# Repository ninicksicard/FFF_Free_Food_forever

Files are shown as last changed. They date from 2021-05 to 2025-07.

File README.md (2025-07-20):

# FFF_Free_Food_forever

bioreactor

Automated spirulina bioreactor. When your refrigerator also make your food.
 
This is my take on solving world unger.

Spirulina is nutritive, cheap and easy to grow. Making a spirulina bioreactor could continuously produce a food source with minimal ressources.

Current status : 
working prototype with some manual input. 
Total cost is less than 220$ and can be lowered.
working cost is pretty low : 
  less than 7$/month of electricity
  cost of growth medium is uncertain now. seems to be less than 30$/months.
  in canada, water is free, but elsewhere it should be taken into account.

---> See the Fabrication Guide pdf for a better look <----

To make your own : 
1. gather all the parts listed in the parts list.

2. order a pcb on jlcpcb with the Gerber Files for the motherboard
diagram
pcbdiagram
PCB
3. order a spirulina starter kit or get some live culture from a friend. 
sample backup
4. assemble the parts following the instructions. electronic soldering is required.

5. load the software on the microcontroller following instructions. 


6. prepare the growth medium and make sure the system is working properly.
7. begin spirulina culture.
first inoculation
8. wait until the population is dense enough
100x spirulina microscope(streight strain) (2)
9. consume the extracted spirulina every days or discard the surplus.


Spirulina reliability as food source.
It is far from a perfect food source, but it is better than fast food. 100L should be barely enough to survive on. 
with a 200L culture, you should produce about 40g of dried spirulina every day. with that amount, following vitamins are produced. (percentage of recommanded daily values)

Vtamin A	retinol 	15%							
Vitamin B1	79%
Vitamin B2	113%
Vitamin B3 32%
Vitamin B5	28%
Vitamin B6	11%
Vitamin B7	125%
Vitamin B9	0%
Vitamin B12	1100%
Vitamin C	4%
Vitamin D 0%
Vitamin E 13%
Vitamin K	9%

As stated, it is definetly not a perfect or proper food source, but it is way better than nothing. Calories should come from some other food, but it is not hard to come-by for cheap. 

Taste 
When rinsed properly, fresh and mixed with water, it feels and taste like drinking water. 

# DIY Spirulina Bioreactor

## Table of Contents
1. [Introduction](#introduction)
2. [Features](#features)
3. [Installation](#installation)
4. [Usage](#usage)
5. [Contribution Guidelines](#contribution)
6. [Troubleshooting](#troubleshooting)
7. [License](#license)
8. [Acknowledgements](#acknowledgements)
9. [Documentation and Data](#docs-data)

## Introduction 
Welcome to the DIY Spirulina Bioreactor project. Spirulina is a nutrient-rich, easy-to-grow microalgae that serves as an excellent food source. Our project aims to tackle world hunger by providing a cost-effective solution: a DIY Spirulina Bioreactor. This bioreactor automates the process of Spirulina cultivation, offering a sustainable food production method with minimal resource requirements.

## Features 
The Spirulina Bioreactor boasts several features:
- Efficient and cheap Spirulina cultivation
- Automated process requiring minimal manual intervention
- Low total and operational costs
- Utilization of sustainable and accessible resources

## Installation 
Setting up your own Spirulina Bioreactor involves a few steps, including gathering necessary parts, ordering a PCB, procuring a Spirulina starter kit, assembling the parts, loading the software on the microcontroller, and preparing the growth medium. Detailed instructions and a list of materials are provided in the [Fabrication Guide](link-to-guide-here) PDF.

## Usage 
Once the setup is complete, the bioreactor can be used to cultivate Spirulina. Detailed instructions on Spirulina cultivation, maintenance, and extraction are provided in the guide. We also provide information on how to handle the harvested Spirulina.

## Contribution Guidelines 
We welcome contributions to improve the project. This could include bug fixes, feature enhancements, or even sharing your experience of building and using the bioreactor. Please make sure to adhere to the project's code of conduct.

## Troubleshooting 
We provide a list of common issues encountered during the setup or usage of the bioreactor, along with their respective solutions. If you face a problem not listed there, please raise an issue, and we'll address it promptly.

## License 
This project is licensed under the MIT license.

## Acknowledgements 
We would like to thank the open-source community for their continuous support and inspiration that made this project possible.

## Documentation and Data 
All supplementary documentation can be found in the `docs/` directory, including fabrication instructions and research papers. Data sets and spreadsheets are now located in the `data/` folder. Media files showing the progression of the project are under `media/`.

---

For further questions or clarifications, please contact us at [email@example.com](mailto:email@example.com).

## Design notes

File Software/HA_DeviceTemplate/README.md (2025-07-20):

# HA_DeviceTemplate

This project provides a skeleton for controlling an ESP32S3 based device with MicroPython.  Use it as a starting point for your own hardware projects.  Wi‑Fi and MQTT credentials are no longer stored in the repository.  Instead they are loaded from environment variables or local configuration files that are ignored by git.

## Configuration

### Wi‑Fi
Wi‑Fi networks are read from a JSON configuration file.  The path can be specified with the environment variable `WIFI_CONFIG_PATH`.  If not set, `/networks.json` is used.  A template file is provided as `networks.example.json`:

```json
{
    "schema": 2,
    "known_networks": [
        { "ssid": "YOUR_WIFI_SSID", "password": "YOUR_WIFI_PASSWORD", "enables_webrepl": false }
    ],
    "access_point": {
        "config": {
            "essid": "Micropython-Dev2",
            "channel": 11,
            "hidden": false,
            "password": "CHANGE_ME"
        },
        "enables_webrepl": false,
        "start_policy": "fallback"
    }
}
```

Copy this file to `networks.json` and fill in your credentials.  Because `networks.json` is listed in `.gitignore`, it will not be committed to version control.

### MQTT
The MQTT client reads its connection settings from environment variables:

- `MQTT_BROKER` – hostname or IP of the broker
- `MQTT_CLIENT_ID` – client identifier (defaults to a value derived from `machine.unique_id` if unset)
- `MQTT_USERNAME` – MQTT username
- `MQTT_PASSWORD` – MQTT password

You can create an optional `.env` or `mqtt_config.json` (both ignored by git) and load the variables before running the code.

An example configuration file is provided as `mqtt_config.example.json`:

```json
{
    "MQTT_BROKER": "mqtt.example.com",
    "MQTT_CLIENT_ID": "ESP32S3_example",
    "MQTT_USERNAME": "homeassistant",
    "MQTT_PASSWORD": "YOUR_MQTT_PASSWORD"
}
```

Copy this file to `mqtt_config.json` and update it with your credentials.

## Running Tests
Run `pytest -q` to execute the test suite (currently empty).

## Print Control
The `print_control` module allows global control over the built-in
`print` function.  Importing the module overrides `print` so you can
disable all output or log it to a file::

    import print_control
    print_control.set_print_enabled(False)
    print("This won't appear on stdout")
    print_control.set_log_to_file(True, "mylog.txt")
    print("This will be written to mylog.txt")

## Stopping Timers
The application schedules most of its work using ``machine.Timer`` instances.
Once ``boot.py`` finishes execution, these timers continue to run in the
background. Pressing ``Ctrl-C`` immediately after boot does **not** stop them
because the boot script has already returned. To clean up running timers from
the REPL, call::

    import bootproc
    bootproc.kill_all_timers()

Alternatively enable automatic cleanup by starting the keyboard interrupt
monitor::

    bootproc.start_keyboard_interrupt_timer()

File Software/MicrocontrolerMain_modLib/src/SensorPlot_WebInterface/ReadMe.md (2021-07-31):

# SensorPlot WebInterface

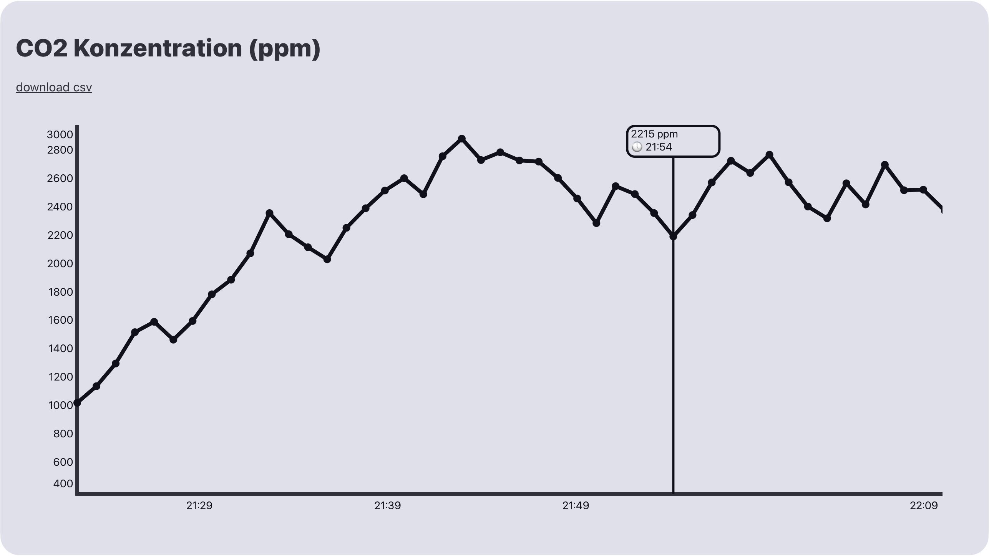
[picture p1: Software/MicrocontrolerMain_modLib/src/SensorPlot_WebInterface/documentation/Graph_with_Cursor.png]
Sensor-Graph with Info-Cursor Image Sensor-Graph with Info-Cursor


## Description
The SensorPlot_WebInterface C++ library is made to be used on any Ardunio like microcontroller to make up a webinterface.
This interface is able to display up to 32 Plot-Graphs which represent sensor measurements. Each graph provides a *download csv* link which triggers a download of a CSV-File, containing all tracked Plot-Data of this sensor.

As a summory on the top is a view, containing the latest sensor measurements and a smiley which represents the state of those values. If they are not good or even bad the smiley changes its mood from happy to neutral or sad. These thresholds, as well as Name, Unit, etc. can be configured when adding a Plot.

By hovering over the graph, the Info-Cursor will show up and display detailed information about the measurement at this time. Displayed will be the exact value and time at which the measurement has been made.

Furthermore the webinterface also supports light and dark mode, automatically detected by the system preferences as well as a mobile and desktop mode, which is determined by the window width. 

---

## How to use it
This project depends on the ESP8266WebServer lib to create the server.
This repo contains a SensorPlot_WebInterface_ConfigExample.ino file where you can check out an easy example how to implement this library.
More detailed information about how to use it are here:

#### Step 1 - configuration
After instantiating the ESP8266WebServer and the SensorPlot_WebInterface you have to call the ``interfaceConfig("title", "input field", "perform action")`` method which takes 3 arguments.
1. The Website Title, wich should be displayed in the browser
2. Input Field, which is the placeholder text for the callback input field in the webinterface
3. Perform Action, which is the text of the button, which triggers the callback with the input field's text as param

#### Step 2 - add plots
Next you have to define all the Sensor-Plots you want to display on the interface. You can add up to 32 of them.
They can be added by calling the ``addPlot("Name", "Unit", interval, goodThreshold, badThreshold, min, max, stepsize, cycleDuration, cycleStepsize, &measurementsCount, measurements, &measurementsTimestamp)`` method which takes 13 arguments.

|Argument | Type | Description|
|--|--|---|
|1. The Sensor Name | String | how this measurement is called (e.g. "CO2 Concentration")|
|2. Sensor Unit | String | what this value is measured in (e.g. "ppm - parts per million")|
|3. Reload Interval | Int | in which interval shoud the webinterface reload the sensore data form the server (often same as cycleDuration)|
|4. lower Threshold | Int | down to which value can this measurement be considered as good|
|5. upper Threshold | Int | up to which value can this measurement be considered as good|
|6. Min Graph-Value | Int | the minimum Y-Axis value that is static on the graph (gets overriden, when reaching this border)|
|7. Max Graph-Value | Int | the maximum Y-Axis value that is static on the graph (gets overriden, when reaching this border)|
|8. Graph Stepsize | Int | at which interval should the Y-Axis labels be displayed (e.g. 0 - 200 - 400 - 600 [stepszie = 200])|
|9. Cycle Duration | Int | in which interval are the values measured in seconds (e.g. cycleDuration = 60 | measurements are 1 minute apart)|
|10. Cycle Stepsize | Int | at which interval should the X-Axis labels be displayed (e.g. cycleStepsize = 300 | the labels are 5 minutes apart)|
|11. Measurements Counter Pointer | *Int | a pointer onto the counter of measurements tracked from this sensor|
|12. Measurements Pointer | *Float | a pointer onto the array containing the measurements from this sensor|
|13. Measurements Timestamp Pointer | *Int | a pointer onto the timestamp of the last measurement done with this sensor (millis since last measurement to calculate the time)|

#### Step 3 - response setup
The final step is to call the ``serverResponseSetup(&server, &callback)`` method which takes just 2 arguments.
1. A pointer onto the ESP8266WebServer
2. A pointer onto a method, returning an int, which gets called when the webinterface triggers the callback.

This callback function receives a String containing the input text from the input field on the website. By checking the input in this method you can trigger or execute any operation you like. Just make sure to return a 0 when the input is invalid and return 1 when it is valid. This will get looped through to the interface and changes the input fields color to green or red.

---

## Why has it been developed
This library was developed as part of an open source project at the Trier University of Applied Sciences Environmental Campus Birkenfeld.
The idea is to provide as many schools, universities as well as private person with a budget friendly way to build their own CO2-Concentration Measurement Stations. This should indicate when it's time to get fresh air, which got even more important throught to the Covid-Pandamic. 
This lib was created to allow a user friendly interaction and to provide an easy way for everyone checking the values of the past couple of hours.

For further information, please check out this website - [CO2 Ampel](http://www.co2ampel.org/)
Here you will find plans and descriptions to build your own device, when you like.

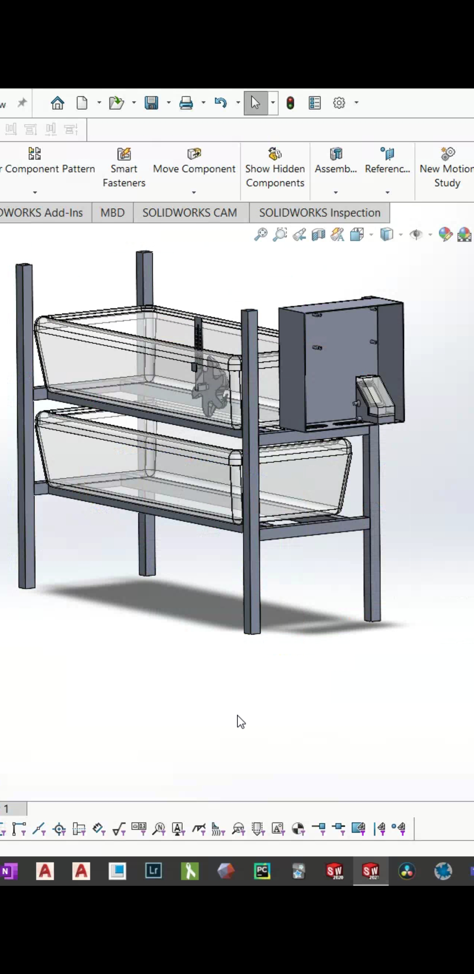
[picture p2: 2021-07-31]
docs/progression medias/3D model concept.jpg

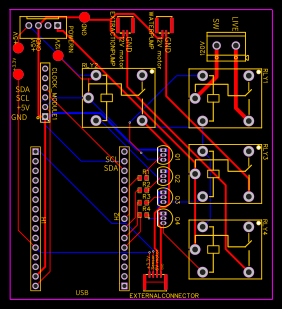
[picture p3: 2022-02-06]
Hardware/electronic/fdd8c61e862d43c1a90568aa42baffc7.png

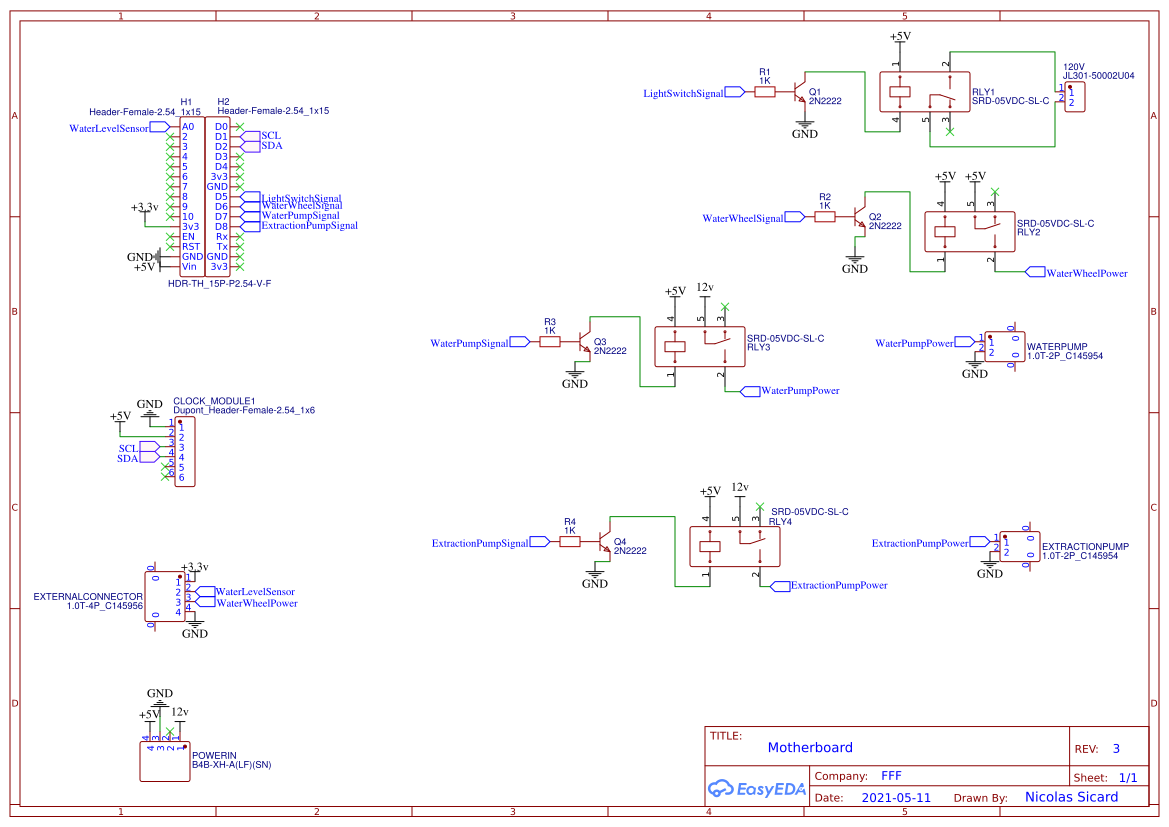
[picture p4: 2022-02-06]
Hardware/electronic/a6cdc383c2d447928fe49a9db9fc658a.png

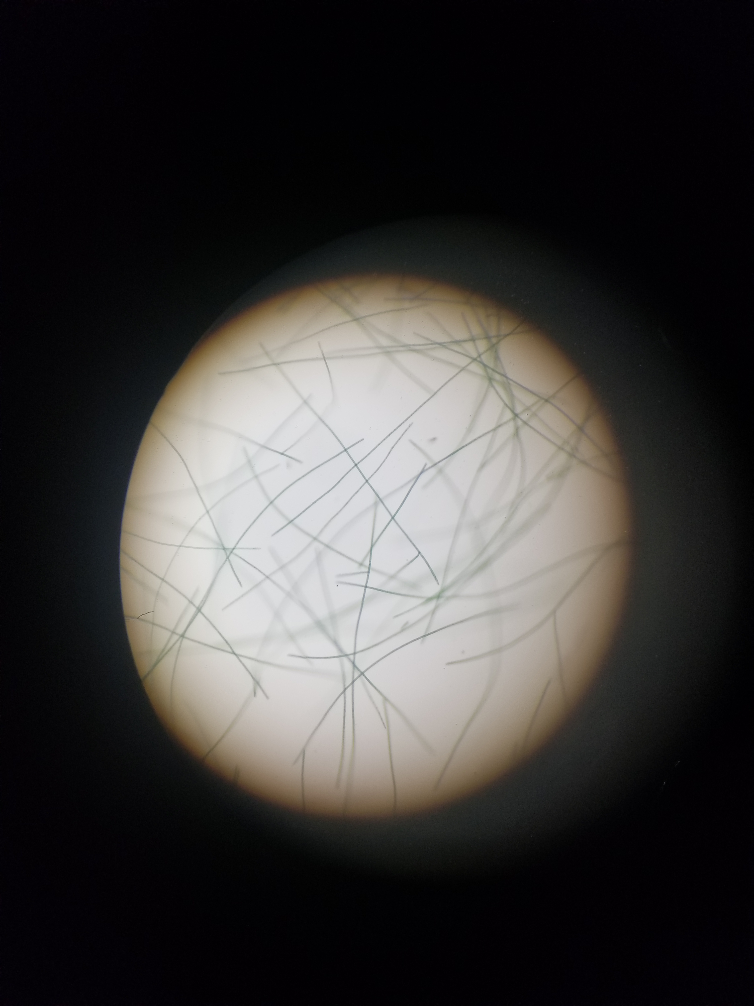
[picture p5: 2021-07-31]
docs/progression medias/100x spirulina microscope(streight strain) (2).jpg

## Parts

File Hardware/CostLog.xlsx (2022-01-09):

 |  | Total |  | $956.63
183.008
selection price | Include | Item | technical name/model number | lot price | lot size or meters | quantity/bioreactor | unit price | url
0 | FALSE | PH Sensor |  | $20.00 | 1 | 1 | $20.00
0 | FALSE | PH Sensor |  | $9.52 | 1 | 1 | $9.52 | https://www.aliexpress.com/item/32813510050.html
0 | FALSE | Thermometer | DS118B20 | $13.00 | 3 | 1 | $4.33
0 | FALSE | Thermometer | DS118B20 | $2.49 | 1 | 1 | $2.49
 | FALSE | resistor for thermometer
0 | FALSE | NodeMcu |  | $6.00 | 1 | 1 | $6.00 | https://www.aliexpress.com/item/2046539452.html
$3.83 | TRUE | NodeMCU |  | $38.28 | 10 | 1 | $3.83
0 | FALSE | Nodemcu |  | $327.74 | 100 | 1 | $3.28
0 | FALSE | Growlight | 100w each 480 needed max | $54.99 | 2 | 4 | $109.98 | https://www.amazon.com/Spectrum-Growing-Vegetables-Greenhouse-Hydroponic/dp/B082QQJ82V
$39.34 | TRUE | Growlight | 100w each 480 needed max | $78.68 | 4 | 2 | $39.34 | https://www.aliexpress.com/item/32847579349.html
$3.42 | TRUE | light socket |  | $1.71 | 1 | 2 | $3.42 | https://www.aliexpress.com/item/1005002524429990.html
0 | FALSE | water pump |  | $30.00 | 1 | 1 | $30.00
0 | FALSE | dosing pump |  | $50.00 | 4 | 3 | $37.50
$10.88 | TRUE | dosing pump |  | $16.32 | 3 | 2 | $10.88 | https://www.aliexpress.com/item/4000602374795.html
0 | FALSE | dosing pump |  | $6.26 | 1 | 3 | $18.78
0 | FALSE | 6 channel relay module | 12v 6 channel version | $4.47 | 1 | 1 | $4.47 | https://www.aliexpress.com/item/32649659086.html
0 | FALSE | 16 channel Relay Module | SainSmart 16-Channel Relay Module | $23.36 | 1 | 1 | $23.36 | https://www.amazon.ca/gp/product/B0057OC66U/ref=ppx_yo_dt_b_asin_title_o00_s00?ie=UTF8&psc=1
$8.49 | TRUE | 4 Channel I2C A/input | ADS1115 PGA | $16.99 | 2 | 1 | $8.49
0 | FALSE | 16 channel I2C output | MCP23017 | $2.12 | 1 | 1 | $2.12 | https://www.aliexpress.com/item/32957655097.html
0 | FALSE | air compressor |  | $10.00 | 1 | 1 | $10.00
0 | FALSE | container | 48x22x7 | $72.00 | 12 | 1 | $6.00
0 | FALSE | clear lid |  | $60.00 | 1 | 1 | $60.00 | https://www.uline.ca/Product/Detail/S-22486/Building-Supplies/Plexiglas-Acrylic-Sheets-24-x-48
$37.38 | TRUE | 50Lcontainer |  | $18.69 | 1 | 2 | $37.38 | https://www.canadiantire.ca/en/pdp/type-a-clarity-under-bed-container-50-l-1422056p.1422056.html
$23.22 | TRUE | heating mat |  | $11.61 | 1 | 2 | $23.22 | https://www.aliexpress.com/item/4000714399275.html
$11.52 | TRUE | thermal insulation |  | $23.03 | 2 | 1 | $11.52 | https://www.aliexpress.com/item/4001365895669.html
0 | FALSE | air pump | 370a mini air pump | $9.28 | 2 | 1 | $4.64 | https://a.aliexpress.com/_mr6hHd3
0 | FALSE | waterwheel motor |  | $5.16 | 1 | 2 | $10.32 | https://www.aliexpress.com/item/32991622456.html?spm=a2g0o.placeorder.0.0.64f4321emhDq1a&mp=1
$10.59 | TRUE | 12v power supply | 12V >2A | $10.59 | 1 | 1 | $10.59 | https://www.aliexpress.com/item/33042313383.html
$1.36 | TRUE | 5V power supplly | 5v >2A | $1.36 | 1 | 1 | $1.36 | https://www.aliexpress.com/item/1005001507883626.html
$13.99 | TRUE | tubing | 5mmID x 7mm OD | $13.99 | 5 | 5 | $13.99
$18.99 | TRUE | Fertilizer | with cobalt | $18.99 | 1 | 1 | $18.99 | https://www.amazon.ca/Indo-Cal-Mag-Supplement-Minerals-Magnesium/dp/B08FMCVPB2

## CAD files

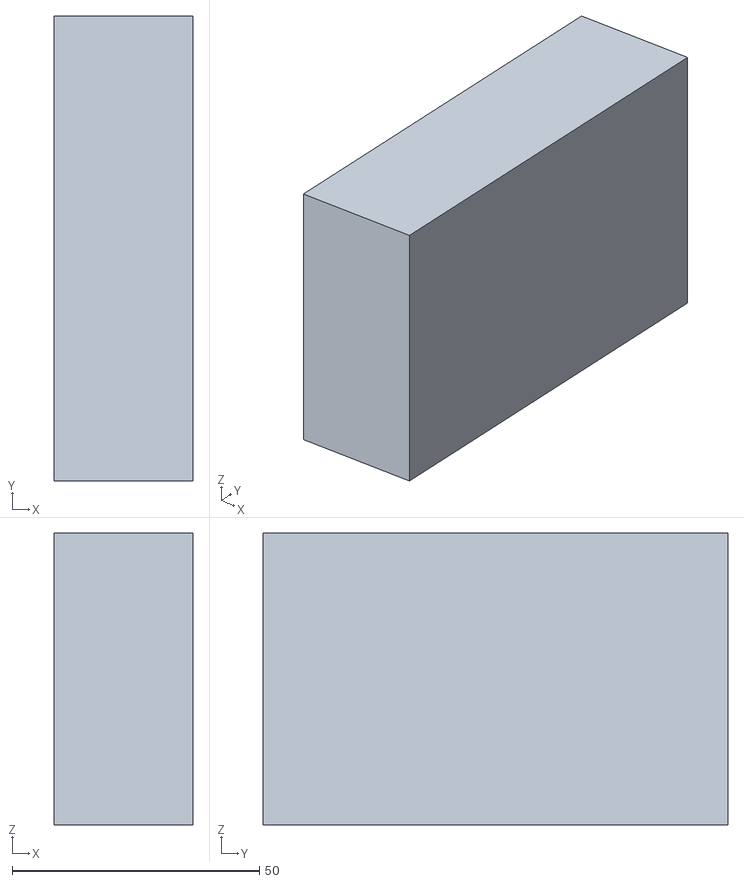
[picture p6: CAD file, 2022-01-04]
Hardware/STL/electronic case^Bioreactorwithout main container - powersupplycover-1.STL
28.0 x 94.0 x 59.0

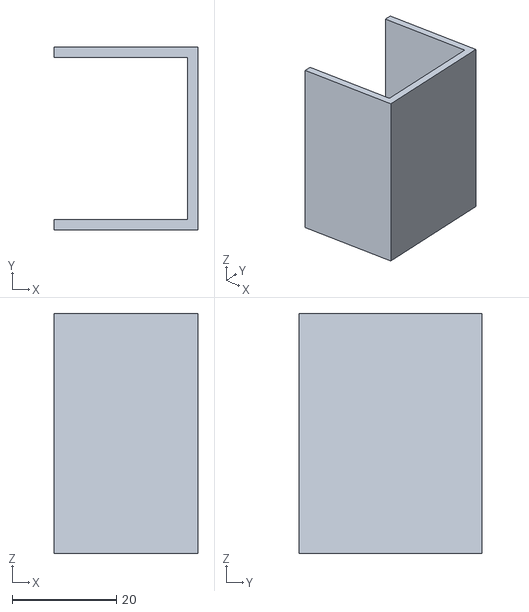
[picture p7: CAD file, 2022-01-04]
Hardware/STL/electronic case^Bioreactorwithout main container - intletcover-1.STL
27.5 x 35.0 x 46.0

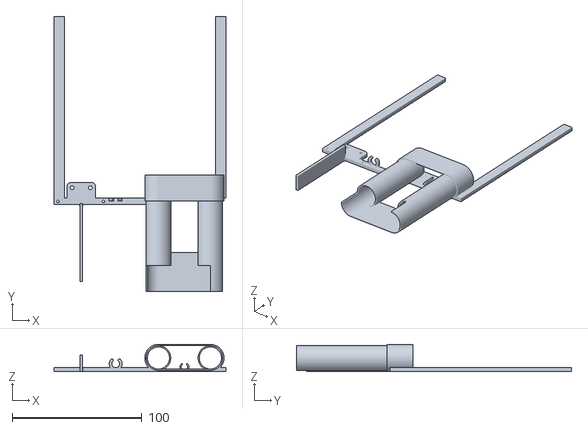
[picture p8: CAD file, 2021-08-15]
Hardware/STL/Sensor Module full.STL
132.4 x 212.0 x 21.0

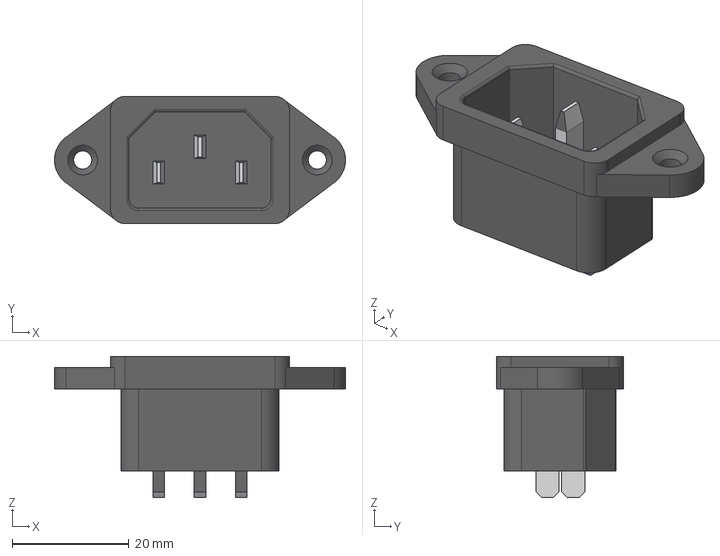
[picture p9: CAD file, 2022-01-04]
Hardware/electronic/Kettle_Plug_Female_IEC_C14.step
49.9 x 21.8 x 24.2 mm

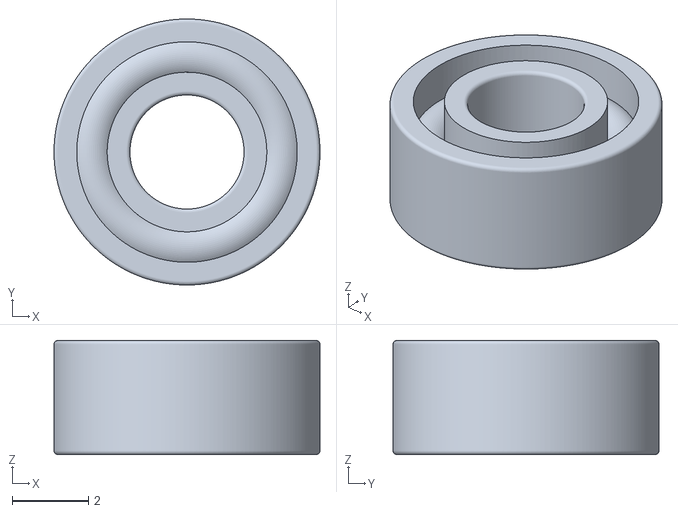
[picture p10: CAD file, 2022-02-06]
Hardware/STL/water_side - radial ball bearing_68_am-3.STL
7.00 x 7.00 x 3.00

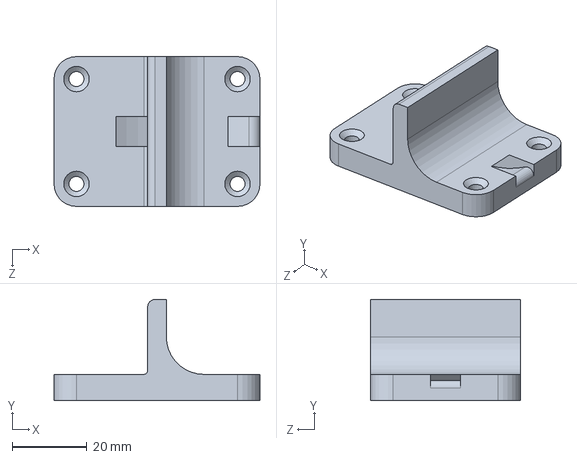
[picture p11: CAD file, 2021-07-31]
Hardware/Complete system/universal motor mount.SLDPRT
55.0 x 27.0 x 40.0 mm

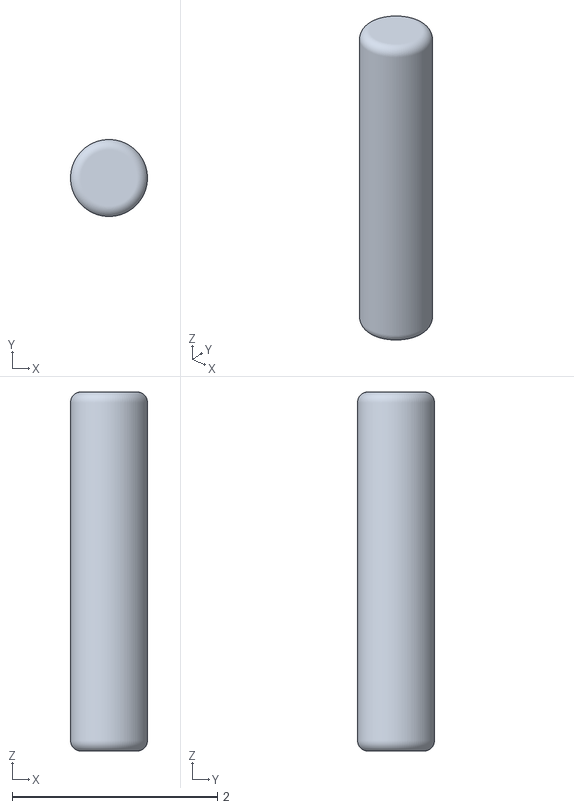
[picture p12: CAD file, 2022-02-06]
Hardware/STL/water_side - motor N20-2 втулка центральной шестерни-1.STL
0.75 x 0.75 x 3.50

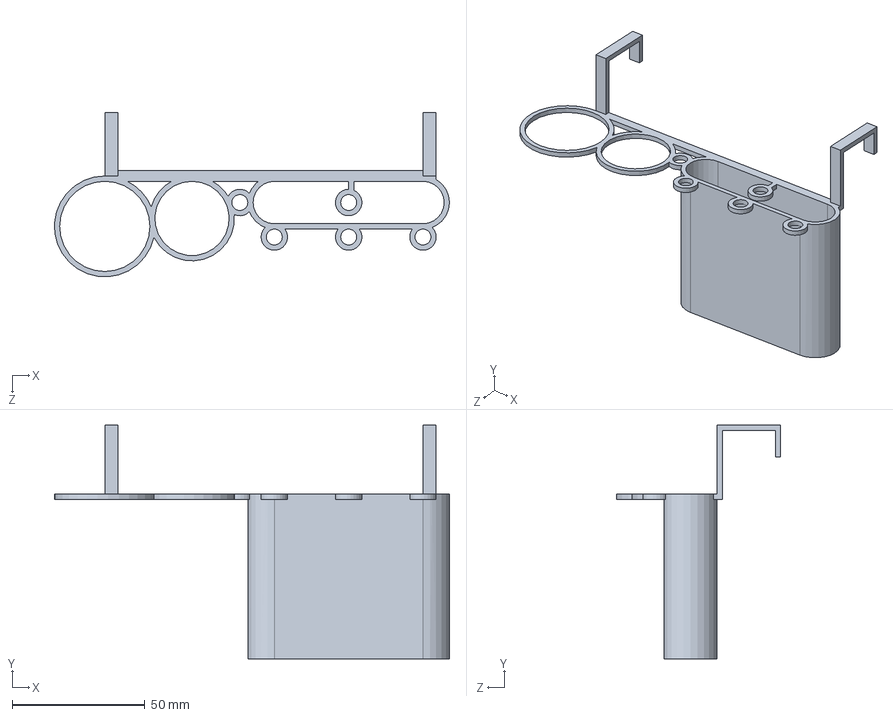
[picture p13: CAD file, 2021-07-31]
Hardware/Complete system/SensorModule.SLDPRT
148.8 x 88.0 x 62.0 mm

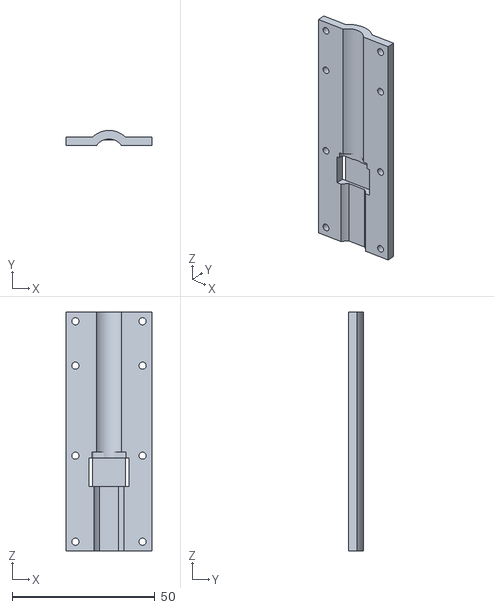
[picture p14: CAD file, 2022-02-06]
Hardware/STL/water_side - top_bearing_clamp-1.STL
30.0 x 5.30 x 83.6

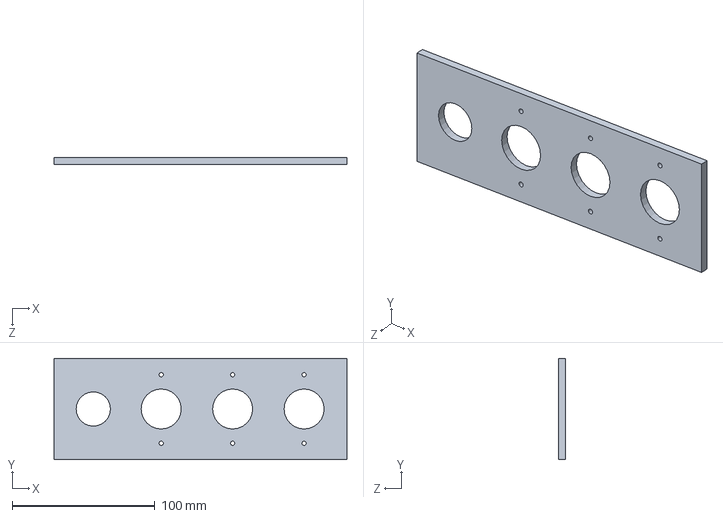
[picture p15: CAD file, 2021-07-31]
Hardware/Complete system/PumpsMount.SLDPRT
205.0 x 71.0 x 5.00 mm

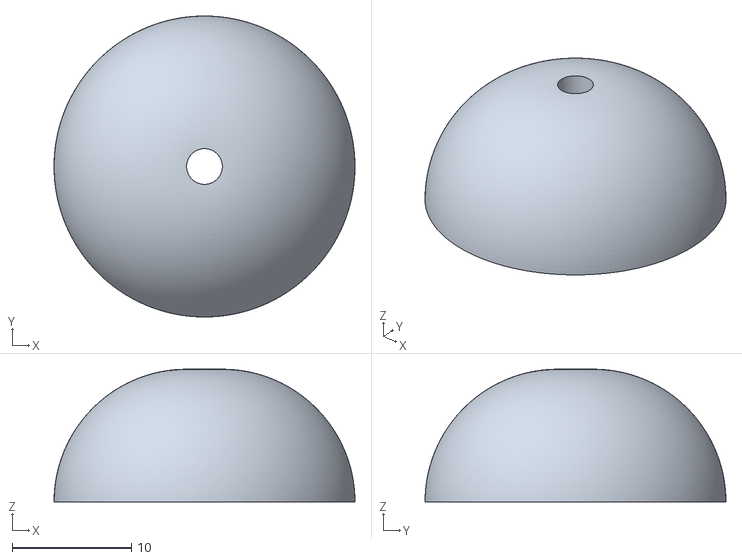
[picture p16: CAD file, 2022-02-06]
Hardware/STL/water_side - splashshield.smg-1.STL
25.3 x 25.3 x 11.1

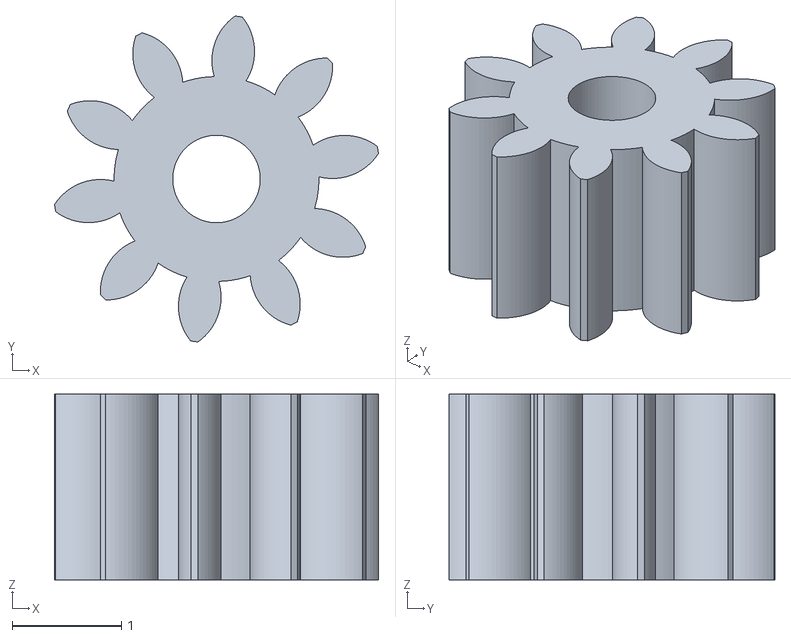
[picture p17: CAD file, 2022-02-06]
Hardware/STL/water_side - motor N20-2 spur gear_iso-6.STL
2.96 x 2.98 x 1.70

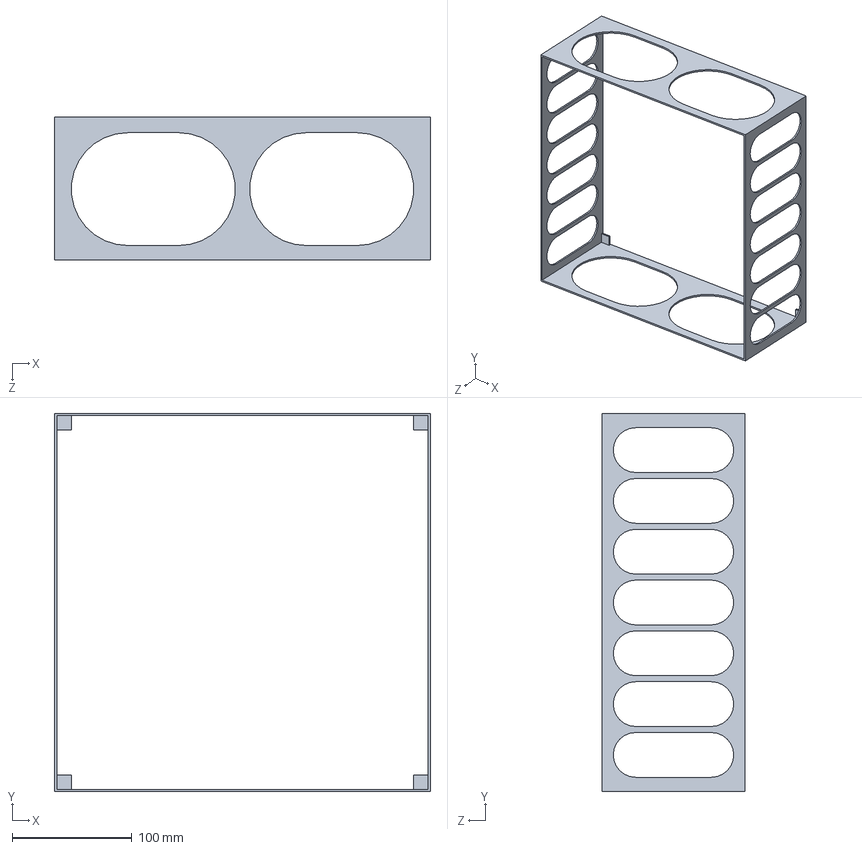
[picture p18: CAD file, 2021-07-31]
Hardware/Complete system/Sides.SLDPRT
313.4 x 315.4 x 119.0 mm

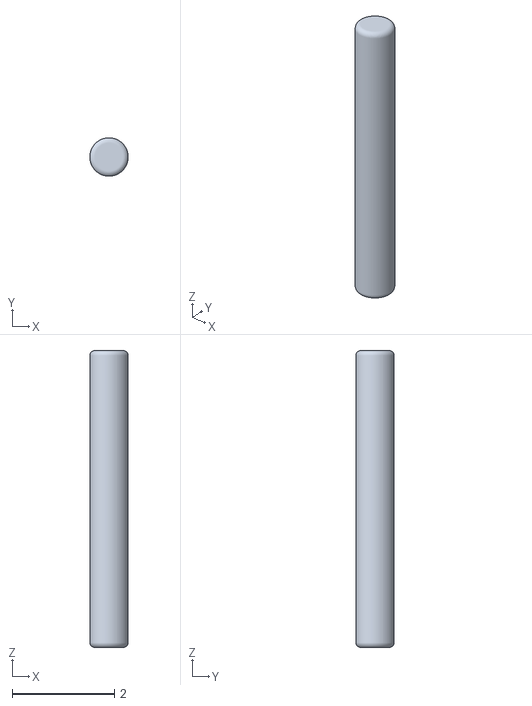
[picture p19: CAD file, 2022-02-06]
Hardware/STL/water_side - motor N20-2 втулка шестерни-1.STL
0.75 x 0.75 x 5.80

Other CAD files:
Hardware/Complete system/bascule.SLDPRT
Hardware/Complete system/water wheel mount.SLDPRT
Hardware/STL/water_side - spacer_long-1.STL
Hardware/STL/water_side - motor N20-2 spur gear_iso-8.STL
Hardware/STL/Extractor^Bioreactor - Copy of Part1^Extractor_Bioreactor-1.STL
Hardware/STL/Extractor^Bioreactor - Copy of Part2^Extractor_Bioreactor-1.STL
Hardware/STL/Extractor^Bioreactor - Copy of Part7^Extractor_Bioreactor-1.STL
Hardware/STL/Extractor^Bioreactor - Part1^Extractor_Bioreactor-1.STL
Hardware/STL/Sensor Module.STL
Hardware/STL/SensorModule.STL
Hardware/STL/SodiumBicaronatepoon.STL
Hardware/STL/Sonsor Module - DensitysensorCappt1-1.STL
Hardware/STL/Sonsor Module - Sensor Module-1.STL
Hardware/STL/Sonsor Module - densitysensor cappt2-1.STL
Hardware/STL/System - 4-Channel_Relay_Module_Mockup-1.STL
Hardware/STL/System - 6331K85_Compact Round-Face DC Motor-1.STL
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

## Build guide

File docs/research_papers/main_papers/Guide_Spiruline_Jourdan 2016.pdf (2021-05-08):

Manuel de Culture Artisanale de Spiruline J.P. Jourdan | Page 1

MANUEL DE CULTURE ARTISANALE DE SPIRULINE (Révision du 8 janvier 2016)

(Détails sur les DERNIERES REVISIONS) (Résumé en anglais : ENGLISH (Résumé en espagnol : CASTELLANO)

SOMMAIRE
PRESENTATION
1) Qu’est-ce que la Spiruline ? SPIRULINE
2) Influence du CLIMAT
3) BASSINS
4) MILIEU de Culture
5) ENSEMENCEMENT
6) Nourriture minérale de la spiruline NOURRITURE
7) Conduite et entretien de la CULTURE
8) RECOLTE
9) SECHAGE
10) CONSOMMATION
11) HYGIENE
12) RECOMMANDATIONS

ANNEXES

CALCULS

BIBLIOGRAPHIE

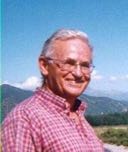
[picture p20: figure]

Manuel de Culture Artisanale de Spiruline J.P. Jourdan | Page 2

LIMINAIRE

L’objectif de ce manuel est de former des formateurs pour diffuser et rendre accessible à un plus grand nombre la culture et la consommation de la spiruline, et aider les futurs « jardiniers » (jardiniers du futur ?) à contrôler un certain nombre de paramètres pour produire à l’échelle familiale, coopérative ou communautaire un aliment dont les qualités nutritionnelles sont aujourd’hui reconnues, mais qui leur reste pratiquement inaccessible, du moins à l’état frais. Il n’est pas de fournir les éléments nécessaires pour une exploitation répondant seulement à des critères de rentabilité commerciale, spécialement en pays à main-d’œuvre chère, car le procédé proposé est très gourmand en main-d’oeuvre du fait de son taux de mécanisation quasiment nul.

Nous avons pratiqué la culture de spiruline à petite échelle dès 1991, dans le but de la mettre à la portée de ceux qui en ont vraiment besoin. Nous souhaitons que ce document, essentiellement basé sur notre expérience personnelle et celles de quelques collègues travaillant de manière similaire, puisse vous initier, guider vos premiers pas dans ce nouveau type de culture.

PRESENTATION

J.P. Jourdan fait part ici de son expérience de près de vingt années de pratique de la culture de spiruline et montre aussi comment appliquer les méthodes du génie chimique pour perfectionner cette production même à petite échelle et sans moyen technique sophistiqué. Il donne une foule de détails permettant de construire l'installation de culture et de conduire sa marche dans des circonstances très variées, mais aussi d'évaluer et d'optimiser le prix de revient de cette micro -algue si demandée actuellement pour ses vertus alimentaires ou autres.

Diplomé du M.I.T., J.P. Jourdan a fait sa carrière dans l'industrie chimique avant de consacrer sa retraite dans le sud de la France au développement de la spiruline en faveur des enfants du Tiers -Monde. Après avoir été "élève ès spiruline" auprès de Ripley D. Fox et de Francisco Ayala, il est membre de Technapet il a collaboré activement avec Antenna Technologie et plusieurs autres O.N.G. dans le domaine de la spiruline.

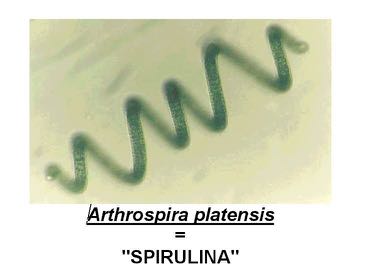
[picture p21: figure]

Manuel de Culture Artisanale de Spiruline J.P. Jourdan | Page 3

Nous vous conseillons de démarrer votre culture à petite échelle, pour vous faire la main, mieux appréhender des phénomènes naturels somme toute très simples, et manipuler des outils de travail qui vous seront d’autant plus familiers que vous les aurez faits vous-même.

Ajoutons que sans pouvoir garantir la qualité de la spiruline produite dans tel lieu, sous tel climat, dans telles conditions, nous pouvons affirmer n’avoir jamais eu connaissance d’un cas de toxicité d’une spiruline produite artisanalement sous les latitudes (entre 0 et 45°) où nous avons travaillé.

QU’EST- CE QUE LA SPIRULINE ?

C’est un petit être aquatique (0,3 mm de long), vieux comme le monde dont le nom scientifique est « cyanobactérie Arthrospira platensis » (ne pas confondre avec la cyanobactérie marine dénommée scientifiquement « Spirulina subsalsa »), qui vit de photosynthèse comme les plantes et prospère naturellement dans les lacs salés et alcalins des régions chaudes du globe. Nourriture traditionnelle des Aztèques du Mexique et des Kanembous du Tchad, plus riche en protéines que la viande, la spiruline est maintenant cultivée dans de grandes usines aux U.S.A., en Inde, en Chine, en Thaïlande, etc., car on lui découvre toujours plus de qualités intéressantes pour l’alimentation et la santé, tant pour les hommes que pour les animaux. Par

Manuel de Culture Artisanale de Spiruline J.P. Jourdan | Page 4

exemple un enfant souffrant de kwarshiorkor (malnutrition) peut être rétabli en lui donnant une cuillérée par jour de spiruline pendant un mois. La spiruline renforce les défenses immunitaires et allège les souffrances des personnes atteintes du Sida. Elle permet aux tuberculeux de mieux supporter leur traitement. La spiruline est aussi utilisée comme ingrédient actif en cosmétique.

Dans la nature, la spiruline n’a besoin pour « pousser » que d’une cuvette argileuse retenant une eau saumâtre et alcaline, sous un climat chaud, et de quelques déjections animales. Les flamants roses de l’espèce « minor » (les plus nombreux) fournissent l’apport en déjections et l’agitation nécessaire pour assurer la croissance de la spiruline naturelle qui est leur aliment exclusif, notamment dans des lacs d’Afrique de l’Est (Rift Valley).

La spiruline se présente sous forme de filaments constitués de cellules juxtaposées. La reproduction de la spiruline, asexuée, se fait par division des filaments.

Pour des détails sur les caractéristiques, les vertus, la fabrication industrielle et le marché de la spiruline, nous vous renvoyons aux ouvrages les plus récents disponibles sur ces sujets, dont le classique « Earth Food Spirulina » de Robert Henrikson, édité par Ronore aux U.S.A (1997) et ceux de Jacques Falquet :
« Spiruline, Aspects Nutritionnels », Antenna Technologie, Genève (2006)
http ://www.antenna.ch/documents/AspNutr2006.pdf, D. Fox : « Spiruline, Production & Potentiel », Editions Edisud (1999), sans oublier « Spirulina Platensis (Arthrospira), Physiology, Cell biology and Biotechnology », d’Avigad Vonshak, aux Editions Taylor & Francis (1997). « Earth Food Spirulina » est maintenant disponible sur
http ://www.spirulinasource.com/ avec mise à jour permanente. « Spirulina in Human Nutrition and Health », par M.E. Gershwin et Ahma Belay, CRC Press (2008) est particulièrement recommandé.

L’usine hawaïenne est décrite dans http ://www.cyanotech.com/.

Voir aussi évidemment les publications d’Antenna Technologie sur www.antenna.ch.

INFLUENCE DU CLIMAT

Les deux paramètres fondamentaux qui contribuent à constituer le climat sont les températures et la pluviométrie. Il ne faut pour autant pas négliger les vents dominants, par exemple le mistral en vallée du Rhône, qui peuvent avoir des conséquences importantes sur l’évaporation d’un bassin de culture, sur la température de l’eau ou la « pollution » de ce bassin par tous les débris et les poussières qu’il peut entraîner.

De même certains éléments comme les haies, la présence de barres rocheuses, de forêts, etc. peuvent entraîner des conséquences importantes sur le microclimat, conséquences qu’il sera bon d’évaluer avant l’implantation d’un bassin... comme d’un jardin potager.

2.1) Température
Les premiers repères concernant les températures sont à peu près les mêmes que pour l’homme, 37°C : température idéale pour pousser. Au-dessus, c’est trop chaud (43°C peut être mortel). En dessous, la vitesse de multiplication baisse avec la température. A 20°C la croissance est pratiquement stoppée. La température du milieu de culture doit donc se situer entre ces deux températures. Plus la « saison » est longue, plus la période de récolte est longue. Les climats continentaux ou d’altitude sont désavantagés.

Le handicap d’un climat trop froid peut être compensé artificiellement, comme pour tous les végétaux. La construction de bassins sous serre peut être d’autant plus intéressante que cet abri constitue non seulement une protection contre le froid, l’évaporation, les insectes et les poussières mais aussi contre les pluies diluviennes, comme les orages, qui peuvent faire déborder les bassins et donc provoquer une perte, ou au moins une dilution

Manuel de Culture Artisanale de Spiruline J.P. Jourdan | Page 5

du milieu de culture.

2.2) Pluviométrie
La conduite de bassins de culture nécessite un minimum de ressources en eau. Les eaux de pluie sont intéressantes car propres et neutres (pas de minéraux en solution). Sous les climats à faible pluviométrie, ou à saison sèche longue, il peut être nécessaire de prévoir une citerne pour stocker de l’eau de pluie et compenser ainsi l’évaporation des bassins. Là encore, il faut un « juste milieu ». Les excès de précipitations devront être prévus en construisant des bassins plus profonds ou en les protégeant. Le manque d’eau est évidemment rédhibitoire. La carence en eau de pluie peut être compensée par l’utilisation d’eaux de provenances diverses, et plus ou moins « chargées » (rivière ou fleuve, nappe phréatique, eaux usées...). Il faudra alors tenir compte de la qualité de l’eau dans la mise au point, puis l’entretien du milieu de culture.

La présence d’une couverture translucide au-dessus des bassins pour éviter une dilution du milieu de culture est une bonne solution dans les régions à fortes précipitations (voir. § 3.2 couverture).

2.3) Climat idéal
Il existe des climats idéaux où il ne fait jamais froid et où les pluies sont harmonieusement réparties et compensent l’évaporation, comme par exemple certains points du versant Est des Andes. Un autre type de climat idéal est le désert au pied de montagnes qui assurent un large approvisionnement en eau, comme par exemple le désert d’Atacama au Chili. L’eau consommée par un bassin sert surtout à maintenir la culture en dessous de 40°C, par évaporation. Dans un climat désertique sans eau la culture est impossible (sauf à importer de l’eau), alors que dans un climat frais la culture sous serre est facile avec une faible consommation d’eau.
2.4) Saisonnalité (Voir Annexe A25 hivernage)
Dans les régions tempérées, l’hiver est généralement trop froid pour cultiver la spiruline, sauf avec chauffage et éclairage artificiels trop coûteux. Même dans des régions chaudes un arrêt annuel peut être rendu nécessaire par l’importance des pluies ou de la sécheresse ou par les vents de sable à certaine saison.
La culture de spiruline sera donc souvent saisonnière.
Durant la mauvaise saison, une « souche » de spiruline devra impérativement être conservée dans son milieu de culture. Les contenants (bocaux, bonbonnes, bassines) devront laisser passer la lumière et être stockés dans un lieu clair mais à l’ombre, ou être sous éclairage électrique. Même si les cultures de spiruline survivent à des températures inférieures à 10°C, voire à de brèves gelées, il est prudent de ne pas les stocker au-dessous de 18°C pendant de longues périodes, car les risques de contamination augmentent.

Le fait que la spiruline prospère en milieu très alcalin présente deux avantages majeurs :
- meilleure absorption du gaz carbonique de l’air
- protection contre les contaminations.
Cette protection nous a été involontairement démontrée au printemps 1997. Nous avions côte à côte deux bassins de spiruline de 10 m², l’un à l’air libre, l’autre protégé de la pluie. Le bassin non protégé ayant débordé a été vidangé et s’est rempli d’eau de pluie, laquelle a été colonisée par des algues vertes unicellulaires (chlamydomonas) et nombre d’animaux (vers rouges, larves de moustiques, insectes nageurs). L’autre bassin a gardé ses spirulines sans contamination. Cependant il ne faut pas croire que seule la spiruline peut croître dans son milieu de culture : d’autres algues, des microorganismes et des animaux peuvent y vivre, d’où nécessité de surveiller les cultures du point de vue contaminants, surtout aux changement de saisons.

BASSINS

Où implanter les bassins ? Il faut respecter quelques règles pas toujours évidentes : pas sous des arbres, ni en un lieu inondable, ni près d’une route ou d’une industrie (pollution). A l’abri des curieux, souvent ignorants et pas toujours bien intentionnés. Un terrain plat facilitera le travail, de même que la proximité de l’eau, etc. Il vaut la peine de réfléchir avant de décider.

3.1) Construction des bassins de culture

Pour une production familiale ou artisanale on peut se contenter de bassins de petite taille, sans agitation à roue à aube, sans chicane médiane. Il y a alors de nombreuses façons de construire un bassin adéquat, variables selon les conditions locales.

Le bassin ne doit pas comporter d’angles vifs, mais des formes arrondies (au moins aux extrêmités dans le cas de bassins rectangulaires). Le fond doit être aussi plan que possible,

Manuel de Culture Artisanale de Spiruline J.P. Jourdan | Page 6

avec une très légère pente vers un endroit plus creux d’accès facile (pour faciliter la vidange). Les bords du bassin doivent être au-dessus du niveau du terrain, pour réduire l’entrée des poussières et des animaux, et au moins 20 à 40 cm au-dessus du fond : mieux vaut prévoir une profondeur assez forte, pour encaisser les pluies, faciliter les transferts entre bassins et éventuellement l’autoépuration biologique du milieu de culture. Les bassins, surtout les plus profonds, doivent faire l’objet de précautions pour éviter l’accès des petits enfants. Il faut aussi faire en sorte qu’on ne puisse pas confondre les bassins avec un dépotoir, mésaventure qui est malheureusement arrivée dans plusieurs pays.

Une des plus grosses difficultés pour réussir un bassin est l’aplanissement du fond : en fait c’est là où réside surtout la limitation en surface pour un artisan ne disposant que d’outils ordinaires (pioche, rateau, règle et niveau à bulle). Pour les grands bassins les entreprises utilisent le laser qui facilitent bien le travail.

Une variante, qui ne sera pas décrite ici car assez peu adaptée aux conditions artisanales, consiste à faire la culture en lame d’eau coulant sur un plan incliné.

3.1.2) En bâches plastique

Une épaisseur de film de 0,25 mm minimum, et de préférence 0,5 mm, est recommandée. Le film (polyéthylène, EVA, PP, EP, PVC, caoutchouc EPDM), de qualité alimentaire (ou au moins non toxique), sans plastifiant et résistant aux ultraviolets, peut être simplement fixé sur un cadre en bois ou en tubes d’acier ou de PVC, ou soutenu par un muret en planches, briques, parpaings (de préférence cimentés et sur fondation béton), éventuellement terre crue stabilisée (pisé, »banco »). En fait la solution muret en dur est la mieux en cas de risque d’attaque par des rongeurs ou des termites. Eviter le plus possible les plis dans les angles donnant des zones qui ne seraient pas bien agitées ou aérées. Il est recommandé de cimenter le sol supportant le bassin ou de le couvrir d’une couche de sable de rivière ou latérite broyée bien damée. Si l’on doit utiliser du film plastique mince, le protéger du contact direct avec le sol et la maçonnerie, par exemple avec un feutre type « géotextile » ou deux ou trois couches de film usagé. Il existe un film PVC, de qualité alimentaire, de 1,2 mm d’épaisseur et 2 m de large pouvant être assemblé par soudure avec un pistolet à air chaud spécial (nécessite de l’électricité). Le film de caoutchouc EPDM, qui peut se coller, est une bonne solution mais de luxe. Les films épais et soudables ou collables réduisent les plis et facilitent l’installation d’une chicane centrale pouvant être simplement soudée ou collée au fond du bassin, mais ces films ont tendance à rester hors de portée des petits producteurs. La chicane peut être une poche remplie de sable, ou un gros tube placé sous la bâche.

Pour la pose des films et bâches, tenir compte du fort coefficient de dilatation thermique des films plastique (en cas de pose par temps chaud, il y aura rétractation importante par temps froid, et vice-versa).

En cas d’utilisation d’un film de qualité inconnue, faire un essai de culture pour vérifier qu’il n’est pas toxique et qu’il résiste au milieu de culture (voir qualité).

S’il y a des termites il est recommandé de mettre un lit de sable sur une couche de cendres sous le plastique et d’utiliser un muret en dur, ou au moins de traiter le bois, à moins que l’on ne dispose d’un bois naturellement inattaquable ; on peut aussi poser le film sur une dalle d’argile séchée ou mieux de ciment, ou le protéger par du métal. A noter que le chiendent africain est capable de percer le plastique. Il arrive que le plastique ne fuie pas même s’il est

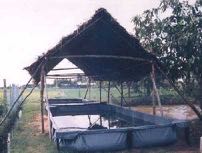
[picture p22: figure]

Manuel de Culture Artisanale de Spiruline J.P. Jourdan | Page 7

percé d’un petit trou, qui se bouche spontanément.
Il est possible de réparer un petit trou avec un mastic noir collant (à sec) vendu dans le commerce à cet effet, ou même avec une « rustine » de ruban adhésif résistant à l’eau.

Les rongeurs peuvent être de redoutables dangers pour les bassins en film plastique non protégé. Pendant des années je n’ai pas eu ce problème à Mialet, puis dans l’hiver 2000-2001 (très doux) 4 bassins ont été percés de multiples trous sur les bords non protégés. Il existe des appareils électriques à ultrasons repoussant efficacement les rongeurs.

Pour pouvoir vidanger et nettoyer un bassin constitué d’une bache plastique supportée par un muret en dur, un moyen facile est de pratiquer un trou dans le sol près du bord de la bâche pour former un point de vidange (puisard).

Photo d’un des premiers bassins (en tissu polyamide enduit PVC) de l’Ecopark, Madurai, Tamil Nadu (Inde), 18 m², 1998 :

3.1.3) En « dur » (béton, parpaings, briques)

Le fond d’un bassin en ciment doit être construit sous forme d’une dalle en béton armé de 10 cm d’épaisseur minimum, de très bonne qualité, sur terrain bien compacté. Les bords du bassin peuvent être en briques, en parpaings ou en béton armé. Eviter les angles vifs. Soigner l’enduit d’étanchéité (un adjuvant imperméabilisant ou une peinture epoxy sont pratiquement indispensable, ou sinon peindre l’enduit ciment à la chaux – dans ce cas laisser en place la chaux avant mise en eau). Il est bon d’attendre quelques jours, bassin plein d’eau, avant d’ensemencer en spirulines (sinon l’alcalinité excessive de la chaux ou du ciment frais peut jaunir très rapidement les spirulines). Il existe des techniques pour construire des bassins de grande longueur (50 à 100 m) sans joint de dilatation. Le mariage béton-film plastique est aussi une solution, soit que le film double le béton pour l’étanchéiser, soit qu’une partie du

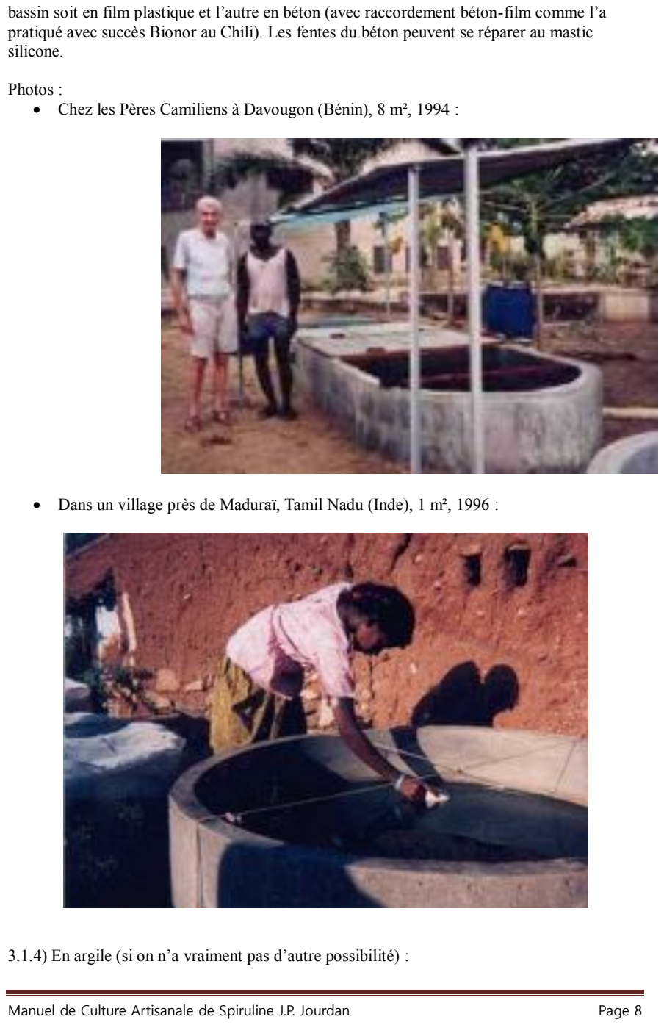
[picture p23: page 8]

Manuel de Culture Artisanale de Spiruline J.P. Jourdan | Page 8

bassin soit en film plastique et l’autre en béton (avec raccordement béton-film comme l’a pratiqué avec succès Bionor au Chili). Les fentes du béton peuvent se réparer au mastic silicone.

Photos :
x Chez les Pères Camiliens à Davougon (Bénin), 8 m², 1994 :

x Dans un village près de Maduraï, Tamil Nadu (Inde), 1 m², 1996 :

3.1.4) En argile (si on n’a vraiment pas d’autre possibilité) :

« Cultivez votre spiruline », manuel de culture artisanale, J.P. Jourdan | 2014

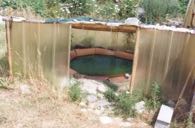
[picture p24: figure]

Manuel de Culture Artisanale de Spiruline J.P. Jourdan | Page 9

Creuser sur 20 cm et faire un talus bien tassé de 20 cm également. Si le terrain n’est pas naturellement argileux, garnir la surface d’une couche d’argile humide de bonne qualité, de 3 à 5 cm d’épaisseur, bien tassée pour éviter les fissures. Garnir les rebords de tuiles ou briques cuites, ou de plastique pour éviter les fissurations lors des baisses de niveau. La spiruline pousse très bien dans un bassin en argile, mais sa pureté bactériologique doit être surveillée de plus près (risques accrus de présence de microorganismes anaérobies au fond car on ne peut pas agiter le fond). L’étanchéité n’est pas complète, mais elle peut être améliorée avec un film plastique même très mince placé sous l’argile.

3.2) Couverture du bassin de culture

En l’absence de toute protection sur le bassin une bonne disponibilité d’eau (pour compenser l’évaporation), l’absence de pluies diluviennes (pluies de plus de 200 mm/jour) et de basses températures sont nécessaires.

Il est en fait souvent utile, voire nécessaire, d’installer une serre ou au moins un toit sur le bassin, permettant de le protéger contre les excès de pluie, de soleil ou de froid, et contre les chutes de feuilles, fientes d’oiseaux, vents de sable et débris divers, tout en lui permettant de « respirer ». Le toit peut être en toile de tente blanche ou en tissu polyamide enduit PVC blanc laissant passer une partie de la lumière mais capable d’arrêter suffisamment la pluie. Il peut aussi être en plastique translucide : film de polyéthylène traité anti-U.V. utilisé pour la construction des serres horticoles, ou plaques en polycarbonate ou fibre de verre-polyester gel-coatée (pour éviter que les fibres sortent). Si le toit est opaque, il faut le mettre suffisamment haut pour que le bassin reçoive assez de lumière par les bords. Le toit est de préférence complété par une fermeture translucide ou des moustiquaires sur les côtés. Si la pluie est tolérable, le toit peut être remplacé par un simple ombrage (filet ombrière, canisse, feuilles de palmier tressées). Le toit peut être flottant (mais sans contact avec la culture) si le bassin est trop large pour qu’on puisse construire une structure fixe pour le supporter.

Manuel de Culture Artisanale de Spiruline J.P. Jourdan | Page 10

Installer une serre consiste à recouvrir le bassin d’un film translucide avec une pente et une tension ou des supports suffisants pour éviter la formation de poches d’eau de pluie et résister

aux tempêtes. Le film peut être supporté par des montants rigides ou des fils de fer ou du grillage (par-dessous et aussi parfois par-dessus). Des orifices d’aération et/ou d’accès doivent être prévus et munis de moustiquaires. Il est généralement nécessaire de prévoir aussi un dispositif d’ombrage (filet ombrière en plastique tissé noir par exemple). Le bois non traité et l’acier galvanisé sont des matériaux convenables pour les structures de serre. Eviter les vis cadmiées (à reflets jaunes). Eviter aussi toute peinture qui ne résisterait pas bien au milieu de culture (la peinture époxy convient). Proscrire les peintures anti-rouille à base de minium (plomb). Poser et tendre le film par temps chaud pour éviter qu’il ne se détende par temps chaud. A noter que certains bois sont attaqués par le milieu de culture, et que selon les pays l’emploi de bois de certaines essences seulement est autorisé dans l’industrie ou l’artisanat alimentaire. Un mode de réalisation économique d’un bassin sous serre consiste à faire un muret en éléments rigides (parpaings ou briques cimentés ou non, planches vissées sur des piquets en acier), à poser le film d’étanchéité en recouvrant le muret et en l’enterrant sur les bords puis à tendre par-dessus un film de serre lui-même enterré sur les bords. Une légère pente (4 %) du film de serre suffit pour que même par pluies très violentes l’eau ruisselle sur le film sans s’y accumuler, à la condition expresse que le film soit tendu (par temps chaud) comme une peau de tambour ou un tissu de parapluie ; la pente peut être fournie par des poutres ou chevrons en bois formant comme une charpente sur le bassin, si le bois est autorisé. N.B. : avec une faible pente, il est probable que la serre ne résistera pas à une chute de neige ou de grêle importante. Pour accéder à un tel bassin et l’aérer il est nécessaire d’installer en au moins un point (mais de préférence deux) une « porte » d’accès, simple cadre vertical sur lequel repose le bord du film qui reste non enterré à cet endroit ; la porte peut être fermée par une moustiquaire (non seulement contre les insectes mais aussi les feuilles mortes). Prévoir la construction pour que la composante horizontale de la tension du film ne fasse pas basculer le muret.Une variante de ce mode de construction consiste à doubler le film extérieur par un film intérieur non tendu présentant un point bas, ce qui permet de mieux isoler la serre et de récupérer l’eau de condensation. Le mode de réalisation le plus économique d’un bassin sous serre utilise le même film (film de serre) pour le fond, les côtés et la couverture. Avec un film de serre de largeur standard (6,5 m) on réalise facilement des bassins jusqu’à 30 m². Le faîte, orienté Est-Ouest, peut être un chevron en bois de 6 x 8 cm, de 5 m de long fixé à environ 1,5 m de haut. Le film est agrafé sur le faîte d’un côté, puis de l’autre avant d’être fixé par liteaux sur le faîte. Aux deux extrémités on place un rebord en planches ou parpaings sur lequel est relevé et fixé solidement le bord du film, et on aménage deux « portes » d’accès à munir de moustiquaires. Le coût des matériaux s’élève à 5 $/m² si la sous-couche de protection est réalisée en film plastique de récupération (usagé), hors ombrage, protection latérale et agitation. L’expérience nous a montré que les sangliers n’attaquaient pas ces structures en film plastique, mais une protection latérale contre les risques de perçage est tout de même recommandée : la placer à au moins 50 cm des bords si elle est en matériau brut pouvant endommager le film lors de ses déplacements par grand vent. Pour assurer la stabilité par grand vent, remplir le bassin d’au moins 20 cm. Il est recommandé de ne pas laisser les côtés du bassin exposés à la lumière car cela pourrait favoriser le développement d’algues étrangères sur les parois éclairées. Ce type de serre permet la récupération automatique de l’eau condensée sur le film de serre (important surtout la nuit dans les climats désertiques). La nuit on peut mettre une couverture isolante souple. Exemple de réalisation en 20m² (à Mialet, en 2000) :

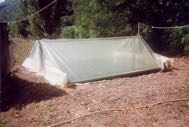
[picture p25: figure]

Manuel de Culture Artisanale de Spiruline J.P. Jourdan | Page 11

Attention à la neige si faible pente et poutre trop faible et/ou trop longue entre deux supports ! Une variante de ce système permet de produire en hiver. On met un isolant fixe sous le fond et sur les côtés jusqu’au niveau de l’eau, et les pentes sont isolées par un isolant multicouche souple aluminisé, ainsi que les portes. L’isolant souple qui recouvre la face Sud est enroulable pendant la journée pour laisser pénétrer la lumière et surtout le soleil qui sera réfléchi par la face Nord restant en place. Un complément de chauffage est apporté par les pompes d’agitation. Des lampes fluorescentes étanches peuvent être supendues sous le chevron pour apporter un complément de lumière de 5hr à 9hr et de 17hr à 21hr..

L’utilisation de film de serre pose la question de sa qualité du point de vue alimentaire. Il ne semble pas qu’il y ait de problème. Certains films (ceux qui sont légèrement jaunes) sont stabilisés contre les UV par un composé à base de cadmium mais d’après nos analyses le cadmium ne migre pas du plastique vers le milieu de culture et ne pollue pas la spiruline.

Un bassin sous serre étanche présente l’avantage de pouvoir être alimenté en gaz carbonique provenant de la combustion de gaz ou d’une fermentation (compost) mais une aération reste nécessaire ne serait-ce que pour maintenir un taux d’oxygène non toxique pour les spirulines.

Une serre ombrable et aérable est idéale en tous climats car elle permet un contrôle maximum tant de la température, de la lumière, de la pluie et de l’évaporation que des insectes et autres animaux, poussières, feuilles mortes ; elle est la protection la plus efficace pour réduire le plus possible la consommation d’eau en climat aride. Sous serre avec ouvertures munies de moustiquaires il n’y a en général pas implantation de larves de mouches Ephydra dans les cultures. Et si une infestation se produit quand même il est facile de laisser monter la température à 42-43°C le temps de tuer les larves sans tuer trop de spirulines.

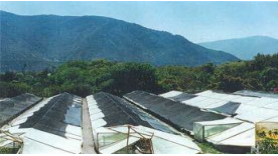
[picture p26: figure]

Manuel de Culture Artisanale de Spiruline J.P. Jourdan | Page 12

Chez Bionor, près de La Serena, Valle de Elqui (Chili), 1997 : seules les têtes des bassins sont en ciment, le reste est en film semi rigide éthylène-propylène (extrêmité noyée dans le béton), les serres sont à charpente bois.

3.3) Nombre et surface de bassins

Mieux vaut construire deux ou plusieurs petits bassins qu’un seul grand : ainsi on pourra en vider un (pour le nettoyer ou le réparer par exemple) sans perdre son contenu, et si une des cultures se contamine, n’est pas en bonne santé ou meurt, un autre bassin permettra de continuer et de réensemencer. Il peut être aussi pratique de puiser dans un bassin pour filtrer sur un autre. Un bassin de service est par ailleurs utile pour préparer les milieux de culture et effectuer des transvasements, ou pour évaporer des purges en vue de recycler les sels, ou encore pour épurer du milieu de culture, mais il n’est pas absolument nécessaire.

Un m² de bassin couvre le besoin en spiruline d’une à 5 personnes selon la dose. Le coût d’investissement au m² décroît quand augmentent la surface unitaire et le rapport surface/périmètre des bassins. Par contre des bassins étroits (largeur inférieure à 3 m) sont plus faciles à agiter et à couvrir. Une surface unitaire de 5 à 20 m² parait pratique au niveau familial ou pour un dispensaire (selon la dose journalière de spiruline, et selon la productivité des bassins). Pour une production artisanale la surface totale des bassins ne dépassera guère 300 m², en général, mais un niveau « semi-artisanal » est envisageable, pouvant dépasser 1000 m² (Annexe 28).

3.4) Agitation du bassin

L’agitation est nécessaire pour homogénéiser, favoriser l’élimination de l’oxygène et assurer une bonne répartition de l’éclairage parmi toutes les spirulines. Sauf en cas de soleil très fort, on peut à la rigueur se contenter d’agitations discontinues, plus ou moins fréquentes (quelques minutes toutes les heures, au moins 4 fois par jour), manuelles avec un balai ou une rame, ou par pompes n’endommageant pas les spirulines (pompes à hélice, vis, palettes, diaphragme ou vortex). Une pompe d’aquarium à entrainement magnétique de 1 à 3 m3l/h, fonctionnant 15 minutes par heure ou par demi-heure (programmateur à horloge) ou même en continu, suffit

Manuel de Culture Artisanale de Spiruline J.P. Jourdan | Page 13

pour agiter 5 à 10 m² de bassin si elle est bien positionnée (orientation de son jet en site et en azimuth) et si les bords du bassin sont réguliers et ses angles arrondis. Une chicane médiane peut faciliter la circulation, mais il faut en général la compléter par des chicanes d’angles redirigeant les flux des bords vers le centre, ce qui complique l’installation : dans un petit bassin de dimensions bien choisies la chicane centrale est totalement inutile. L’installation d’une chicane médiane dans les bassins en bâche plastique (recouvrant la chicane) pose le problème des plis qu’il faut éviter au maximum. Ce problème est minimisé si la chicane est de faible hauteur (20 cm) et ses extrêmités arrondies. Mais certains préfèrent des chicanes fixées sur des plaques de marbre ou granit posées sur la bâche ; dans ce cas il faut veiller à minimiser le by-pass sous la chicane. Un autre mode de réalisation de la chicane consiste à souder une bande de bâche sur le fond, et à la soutenir par des ficelles aux structures de la serre. Il y a aussi des chicanes en sacs remplis de sable et suspendues par des ficelles. On peut aussi mettre un gros tube sous la bâche. On améliore l’efficacité des pompes en faisant passer leur jet dans un tube « Venturi », mais cela complique l’installation . Tous les bassins de la ferme de Consac (Charente Maritime) sont agités avec ce système à venturi.

Nettoyer de temps en temps les crépines des pompes et les recoins du corps des pompes (je préfère enlever le capot qui ne sert qu’à enjoliver les pompes d’aquarium). Avec les souches « ondulées» (Paracas) les pompes vide-cave ordinaires sont utilisables sans risque de casser les filaments ; une telle pompe peut agiter un bassin carré ou rond de 50 m² ; mais ces pompes ne sont pas à entrainement magnétique et comportent donc un joint, ce qui peut provoquer des problèmes d’étanchéité et de corrosion au bout d’un certain temps). Attention : les pompes en 220 Volt nécessitent des précautions pour éviter de s’électrocuter, surtout en serre humide (les constructeurs de pompes d’aquarium demandent qu’on débranche avant de toucher l’eau) ; il est recommandé de brancher le système d’alimentation électrique sur un transformateur « à écran d’isolement » relié à la terre (système utilisé pour les prises de rasoirs dans les salles de bains) ; on peut compléter la sécurité par un disjoncteur différentiel de 30 mV. Des pompes en 12 ou 24 Volts sont préférables…

L’agitation par roue à aubes reste préférée pour les bassins de taille moyenne à grande.

Mieux vaut une agitation discontinue énergique que continue mais faible. Même une agitation énergique sera plus efficace si elle est intermittente car à chaque redémarrage il se produit un brassage, alors qu’en continu la masse d’eau a tendance à se déplacer d’un bloc (sauf si des chicanes sont installées en travers du courant). C’est une bonne pratique d’agiter au balai le bassin au moins une fois par jour, surtout s’il est assez profond, et de brosser le fond et les côté une fois par jour.

Les grands bassins industriels, très longs, sont toujours munis d’une chicane médiane et agités par roue à aubes. Leur surface unitaire maximum est de 5000 m². La technique de construction des roues à aubes mériterait un chapitre spécial mais ne sera pas traitée ici, mais seulement brièvement abordée en Annexe 24.

Les cultures en lame d’eau sur plan incliné (voir. § 3.1) sont agitées par la turbulence due à l’écoulement. Leur construction est délicate et le coût du pompage est lourd.

Un autre mode d’agitation, la cloche à air comprimé s’applique bien aux petits bassins assez profonds, de préférence ronds. Il consiste à faire arriver un débit d’air comprimé (d’un compresseur d’aquarium) sous une cloche lourde posée au fond du bassin (un plat en Pyrex fait bien l’affaire) : la cloche se soulève d’un côté, à intervalles réguliers, en produisant une

Manuel de Culture Artisanale de Spiruline J.P. Jourdan | Page 14

grosse bulle d’air ; en retombant la cloche provoque un certaine circulation du liquide. Sur un bassin rond de 7 m² équipé ainsi avec un compresseur de 300 l/h en marche continue, l’agitation s’est révélée bonne. Un avantage important de ce mode d’agitation est l’absence de fils électriques. Dans la pratique ce mode d’agitation est limité aux bassines ou petits bassins mais peut rendre de vrais services.

Il est nécessaire d’insister sur le fait que le milieu de culture est très corrosif pour les métaux. Pratiquement seul l’acier galvanisé et l’inox type 304 résistent assez bien.

3.5) Containers, bassines, gaines

Il arrive que l’on utilise comme petits bassins des récipients translucides comme des bouteilles, bonbonnes, bassines, gaines en film plastique, containers à jus de fruits (il en existe de 1000 litres). Il faut savoir que la vitesse de photosynthèse paraîtra plus rapide dans de tels récipients parce que le milieu de culture y reçoit la lumière de plusieurs côtés et s’échauffe aussi plus vite. Cela peut être avantageux, mais il faut surveiller la température et le pH de plus près que dans les bassins ordinaires. L’agitation dans de tels récipients se fait de préférence par air comprimé (compresseur d’aquarium).

N.B. Il s’agit là en fait de variantes de « photobioréacteurs » à grand rapport surface/volume permettant d’atteindre des concentrations en biomasse importantes.

3.6) Réparation des films plastique

Il est possible de réparer de petits trous dans les films : nettoyer et sécher une zône autour du trou puis y coller un produit mou et collant (de qualité alimentaire) vendu à cet effet, ressemblant à du chewing gum. Le PVC peut aussi être réparé par rustines collées ou soudées, ou par une bande adhésive résistant à l’eau. Certaines bandes adhésives s’appliquent aussi aux films de polyéthylène. Attention : utiliser des produits de qualité alimentaire.

4) MILIEU DE CULTURE

[N.B. Les logiciels MEDFEED existent pour faciliter les calculs de milieux et de nourriture ; voir en fin de ce chapitre]

4.1) Préparation du milieu de culture

Les spirulines vivent dans une eau à la fois salée et alcaline. L’eau utilisée pour le milieu de culture doit être de préférence potable (mais ne sentant pas fortement le chlore) ou au moins filtrée (sur bougie filtrante ou filtre à sable) et parfois stérilisée aux UV, le plus important étant l’élimination des algues étrangères. L’eau de pluie, de source ou de forage est en général de qualité convenable. Si l’eau est dure, il se produira des boues minérales (plus ou moins abondantes selon la teneur en calcium, magnésium et fer), qui décantent rapidement et ne sont pas particulièrement gênantes pour la culture, à condition toutefois que l’ensemencement initial en spirulines soit assez concentré. Si l’eau est trop dure il vaut mieux la traiter pour éviter des boues gênantes.
Les limites d’alcalinité (ou basicité, les deux termes sont interchangeables) et de salinité permises sont assez larges mais on se place en général vers les minima, pour des raisons d’économie (sauf si la source d’alcali est très bon marché), avec une salinité totale de 13 g/litre et une alcalinité de 0,1 molécule-gramme/litre (b = 0,1) ; mais ces concentrations peuvent être doublées sans inconvénient. Il peut même être avantageux de travailler à une alcalinité double pour atténuer les fluctuations de pH

Manuel de Culture Artisanale de Spiruline J.P. Jourdan | Page 15

dans l’après-midi, surtout en surface ou dans les angles du bassin quand l’agitation est déficiente. Un cas où b = 0,2 est préféré est celui du bassin ouvert démarré en saison sèche : la dilution par la pluie pourra ramener b vers 0,1 ou même en dessous pendant la saison des pluies.

L’alcalinité est habituellement apportée par du bicarbonate de sodium, mais ce dernier peut être remplacé en partie par de la soude caustique ou du carbonate de sodium qui ont d’ailleurs l’avantage de relever le pH initial du milieu de culture (par exemple 5 g/l de bicarbonate de sodium + 1,6 g/l de soude donnent un pH de 10) ; le carbonate de sodium ou la soude caustique peuvent même être la seule source d’alcalinité à condition de les bicarbonater au gaz carbonique ou par exposition à l’air avant usage [attention à ne pas confondre la soude caustique et les « cristaux de soude » du commerce qui sont du carbonate de sodium décahydraté]. Le natron ou trona peuvent aussi être utilisés (voir natron). La salinité complémentaire est apportée par les différents engrais et du sel (chlorure de sodium). Le sel de cuisine iodé et fluoré peut convenir mais souvent il contient jusqu’à 2 % de magnésie insoluble : mieux vaut utiliser un sel n’en contenant pas, pour éviter un excès de boues minérales. De même si le sel apporte trop de magnésium soluble (sulfate par exemple), il y aura formation de sels minéraux insolubles, surtout à pH assez élevé ; des boues minérales excessives peuvent être très gênantes pour une culture qu’on ensemence peu concentrée en spiruline : celle-ci est en effet facilement entraînée par les flocons de boues au fond du bassin sans qu’on puisse la récupérer. C’est aussi une raison qui milite pour ne pas ajouter de calcium en début de culture nouvelle. Par ailleurs l’emploi d’un sel peu raffiné peut être recommandé à cause de sa teneur en oligo-éléments bénéfiques.

En plus du sel et de la soude, le milieu de culture contient des engrais pour assurer la croissance des spirulines, comme en agriculture habituelle : azote (N), phosphore (P), potassium (K) sont les trois principaux éléments, mais soufre (S), magnésium (Mg), calcium (Ca) et fer (Fe) doivent aussi être ajoutés s’ils ne sont pas apportés en quantité suffisante par l’eau, le sel et les engrais. Une analyse de l’eau et du sel est utile pour calculer la dose de Mg, Ca et Fe à ajouter car un excès de ces éléments peut être nocif (perte de phosphore soluble, formation de boues). L’eau, le sel et les engrais apportent souvent assez d’oligo-éléments (bore, zinc, cobalt, molybdène, cuivre, etc.), mais comme ceux-ci sont coûteux à analyser, on préfère, quand on le peut, ajouter systématiquement les oligo-éléments, au moins les principaux sauf le molybdène qui est toujours suffisant.

Les sources d’azote préférées des spirulines sont l’ammoniac et l’urée, mais ces produits sont toxiques au-delà d’une concentration limite (l’urée s’hydrolyse peu à peu en ammoniac). C’est pourquoi on préfère souvent, au moins lors de la préparation du milieu de culture, utiliser du nitrate, dont on peut mettre sans danger une forte dose, constituant ainsi une réserve d’azote à long terme. Les spirulines consommeront d’abord l’ammoniac ou l’urée s’il y en a de disponibles. Une légère odeur passagère d’ammoniac révèle qu’on s’approche de la limite autorisée ; une odeur persistante et forte indique qu’on l’a sûrement dépassée et qu’il faut s’attendre à un mauvais état de la culture (passager ou irréversible selon la dose d’ammoniac).

La spiruline nourrie longtemps à l’urée perd sa capacité à consommer le nitrate. Si on utilise une telle souche, il faudra donc démarrer la culture à l’urée mais sans dépasser les doses permises, c’est-à-dire qu’il faudra la mettre à petites doses fréquentes (en se guidant sur l’augmentation de la quantité de spiruline dans le bassin : mettre au maximum 0,3 grammes d’urée par gramme de spiruline présente).

Note : L’urée est le nom commun du carbamide ; certaines personnes confondant urée et urine, et pouvant éprouver une certaine répugnance à manger de la spiruline fabriquée avec de « l’urée », il peut être préférable, pour elles, de remplacer le terme « urée » par son synonyme scientifique : « carbamide », tout aussi correct mais moins évocateur. Cependant l’urée est un produit très propre et inodore, très employé en agriculture, et très généralement disponible dans le Tiers-Monde.

Le nitrate n’est pas réellement sans risque car il peut se transformer spontanément en ammoniac dans certaines conditions (en présence de sucre par exemple et sans doute d’exopolysaccharides sécrétés par la spiruline elle-même). Vice-versa l’ammoniac (issu de l’urée par exemple) s’oxyde plus ou moins

Manuel de Culture Artisanale de Spiruline J.P. Jourdan | Page 16

vite en nitrate par le phénomène naturel connu sous le nom de nitrification.

Le phosphore est apporté indifféremment par n’importe quel orthophosphate soluble, par exemple le phosphate monoammonique (NH4H2PO4), le phosphate dipotassique (K2HPO4) ou le phosphate trisodique (Na3PO4, 12 H2O), ou encore l’acide phosphorique lui-même ou le tripolyphosphate de sodium (qui s’hydrolysera lentement en orthophosphate). De même le potassium peut être apporté indifféremment par le nitrate de potassium, le chlorure de potassium, le sulfate ou le phosphate dipotassiques. La source de magnésium habituelle est le sulfate de magnésium appelé sel d’Epsom (MgSO4, 7 H2O). Le calcium éventuellement nécessaire est apporté par un peu de chaux éteinte ou de plâtre (sulfate de calcium), ou, mieux, d’un sel de calcium soluble (nitrate, chlorure) ; il faut en mettre de quoi saturer le milieu en calcium à pH voisin de 10, mais pas plus, c’est-à-dire jusqu’à formation d’un léger louche blanc. En cas d’ensemencement d’une nouvelle culture avec peu de spiruline, mieux vaut s’abstenir d’ajouter du calcium au début pour éviter de perdre de la semence entraînée dans les boues minérales.

[Remarque : L’ajout de petites quantités de produits acides (acide phosphorique par exemple) dans un milieu contenant du bicarbonate de sodium et du carbonate de sodium ne réduit pas son alcalinité mais abaisse son pH, c’est-à-dire transforme une partie du carbonate en bicarbonate de sodium sans perte de CO2. Ceci s’applique aussi bien aux ajouts lors de la préparation de milieu de culture que lors de l’ajout de nourriture à une culture. Mais si l’on prépare un mélange où l’apport d’acide est important il y aura perte d’alcalinité et de CO2, ce qui est dommage. Donc mettre l’acide directement dans le bassin.]

On notera la possibilité d’apporter plusieurs éléments à la fois par le même produit, par exemple N et K par le nitrate de potasse, P et K par le phosphate dipotassique, ou S et Mg par le sulfate de magnésium.

On voit l’importance de posséder des rudiments de chimie pour pouvoir jongler entre les différents produits selon leur disponibilité et leur prix. Il suffit en gros de connaître les poids moléculaires et de faire des règles de trois. On peut aussi se passer du concept de poids moléculaire et ne travailler qu’avec les % d’éléments donnés en Annexe A16.

Le fer est apporté par une solution de sulfate de fer acidulée, de préférence à l’acide citrique, ou par du fer associé à un chélatant comme il s’en vend couramment pour les usages horticoles.

Ne pas utiliser les engrais agricoles ordinaires prévus pour être peu solubles (et contenant de nombreuses impuretés), mais seulement les engrais solubles (voir § 6.1, N.B. e et f granulés) ou les produits chimiques purs correspondants. En cas de doute, analyser la spiruline produite pour vérifier qu’elle ne contient pas trop de mercure, plomb, cadmium, ou arsenic).

Les limites de concentration admissibles pour les différents éléments dans le milieu de culture sont données en Annexe 18. Voici un exemple d’analyse de milieu de culture typique d’un bassin en cours de production :

Carbonate = 2800 mg/l
Bicarbonate = 720 mg/l
Nitrate = 614 mg/l
Phosphate = 25 mg/l
Sulfate = 350 mg/l
Chlorure = 3030 mg/l
Sodium = 4380 mg/l
Potassium = 642 mg/l
Magnesium = 10 mg/l
Calcium = 5 mg/l

Manuel de Culture Artisanale de Spiruline J.P. Jourdan | Page 17

Ammonium + ammoniac = 5 mg/l Fer = 1 mg/l

Salinité totale = 12797 mg/l
Densité à 20°C = 1010 g/l
Alcalinité = 0,105 N (molécule-gramme/l)
pH à 20°C = 10,4

Le milieu doit contenir en plus tous les oligoéléments nécessaires, apportés généralement par l’eau et par les impuretés des sels, mais il est prudent, quand on le peut, d’ajouter un complément, au moins en ce qui concerne le zinc (voir Annexe 26). Un peu d’argile peut être un complément utile.

Voici une formule pour milieu de culture neuf (pH proche de 8, voir § 4.7 : ph) convenant pour des eaux de dureté nulle ou faible :

Bicarbonate de sodium = 8 g/l
Chlorure de sodium = 5 g/l
Nitrate de potassium = 2 g/l (optionnel)
Sulfate dipotassique = 1 g/l (optionnel ; 0,1 minimum) Phosphate monoammonique = 0,2 g/l
Sulfate de magnésium MgSO4, 7H2O = 0,2 g/l
Chlorure de calcium = 0,1 g/l (ou Chaux = 0,07 g/l)
Urée = 0,01 g/l (ou 0,034 g/l pour extension de culture, par exemple bassin à géométrie variable, voir Géométrie) ; optionnel s’il y a du nitrate et si la souche est habituée à consommer le nitrate
Solution à 10 g de fer/litre = 0,1 ml/l
Solution d’oligoéléments (selon Annexe 26.2) = 0,05 ml/l

Le fer peut être apporté sous la forme chélatée par 0,008 g de Fétrilon 13 ou de Ferfol 13, ou par 0,005 g de sulfate de fer FeSO4,7H2O par litre de milieu. Si le phosphore est apporté par l’acide phosphorique ou un phosphate sans ammonium, l’urée passe à 0,035 g/l (ou 0,070 g/l en cas d’extension de bassin).

Le nitrate de potassium n’est en fait pas nécessaire, mais il facilite le travail en assurant une réserve d’azote et de potassium. Inversement, si on met du nitrate on peut omettre l’urée (si la souche est habituée à consommer l’urée elle peut demander 3 jours pour s’habituer au nitrate). Si on omet le nitrate, le potassium est apporté par le sulfate dipotassique. Si l’eau est assez riche en sulfates, le sulfate dipotassique peut être réduit à 0,1 g/l et si de plus l’on met du nitrate de potassium il peut même être omis.

La dose totale de chlorure de sodium + nitrate de potassium + sulfate de potassium dépend de l’alcalinité b ; elle doit être environ égale à : 12 – (40 x b), en g/l, avec un minimum de 4 g/l. Cette règle n’est cependant pas absolue puisque le milieu Zarrouk ne contient qu’un gramme de NaCl par litre.

L’alcalinité de 0,1 peut être apportée par 5 g/l de carbonate de sodium ou par 4 g/l de soude, que l’on doit laisser se carbonater avant usage (environ 15 jours à l’air en couche de 15 cm) ; on peut aussi mélanger le bicarbonate de sodium avec le carbonate de sodium ou la soude caustique (voir Annexe 12 et A13 Annexe 13). Retenons qu’un mélange 50/50 de carbonate et de bicarbonate de sodium donne un pH voisin de 10 qui, à la dose de 7 g/l correspondant à une alcalinité de 0,1, convient très bien au démarrage d’une nouvelle culture. Le sesquicarbonate de sodium Na2CO3.NaHCO3.2H2O, produit naturel appelé « trona » aux U.S.A., peut être utilisé à 8 g/l et donne un pH de 10,15 convenant bien aussi (voir § 4.7 : ph). Le natron africain est un trona impur dont l’utilisation tel quel n’est pas toujours recommandée. Les meilleurs natrons sont en général les moins colorés. Avant d’utiliser un natron il faut le tester : vérifier qu’une solution à 20 g/litre filtre bien (sur papier filtre à café) et n’est

Manuel de Culture Artisanale de Spiruline J.P. Jourdan | Page 18

pas trop colorée ni trouble ; doser l’alcalinité et les sulfates. On trouve souvent jusqu’à 30 % d’insolubles (sable) et seulement 30 % de carbonate/bicarbonate. Le sable est facile à éliminer par décantation.
Lorsque le pH d’un milieu en cours de préparation à partir de bicarbonate de sodium et d’eau calcaire doit être relevé par ajout de soude, de carbonate de sodium ou de natron, il est important de n’ajouter le phosphate qu’après la soude, le carbonate de sodium ou le natron, pour éviter la formation d’un précipité en flocons décantant très difficilement ou même ayant tendance à flotter, comme nous l’ont montré des essais faits en octobre 2005 à Montpellier (eau à 116 ppm de Ca).

Le nitrate du Chili potassique (« salitre potásico », granulés colorés en rose par de l’oxyde de fer), produit naturel, peut remplacer avantageusement le nitrate de potassium en apportant une riche dose d’oligoéléments, ainsi que du soufre et du magnésium mais pas de métaux lourds toxiques ; du moins c’était le cas en 1998 (voir analyse en Annexe A16.1). Le Chili exporte aussi du nitrate de potassium purifié et du nitrate de sodium.

Lorsque le milieu contient simultanément les ions ammonium (NH4), magnésium (Mg) et phosphate (PO4), les concentrations de ces ions sont parfois (selon les concentrations et le pH) interdépendantes parce que la solubilité de la struvite, phosphate mixte d’ammonium et de magnésium, est extrêmement faible. Le phosphate mixte insolubilisé reste tout de même disponible pour la spiruline puisqu’il se redissout dès que les conditions le lui permettent, mais s’il y a déséquilibre les concentrations d’un ou deux des trois ions impliqués peuvent être très faibles, ce qui ralentit la croissance et peut même faire mourir la culture (aussi bien par manque de magnésium que de phosphate). Les cristaux de phosphate mixte se déposent normalement avec les boues, mais il arrive qu’on en trouve en surface dans certaines conditions et même parfois dans la spiruline récoltée. Ceci n’est pas grave. Ces cristaux se redissolvent immédiatement par acidification (comme c’est le cas dans l’estomac !). A noter qu’en l’absence d’ammonium les mêmes phénomènes ont tendance à se produire aussi, le phosphate de magnésium étant lui aussi fort insoluble aux pH > 9. Il est recommandé de maintenir une concentration en ion Mg approximativement égale à celle de l’ion PO4.

Lorsque l’eau utilisée est calcaire et surtout très calcaire (100 et jusqu’à 500 mg de Ca/l, voire plus), le phosphate a tendance à précipiter sous forme de phosphates de calcium (très insolubles), et ceci d’autant plus que le pH et la température de la culture seront élevés. Mais les phosphates insolubles peuvent rester en sursaturation (en solution) sans précipiter pendant très longtemps, surtout en présence de matières organiques, et même si parallèlement du carbonate de calcium précipite. Il est donc très difficile de prédire quand le phosphate en solution va être insuffisant pour une bonne croissance de la spiruline. C’est pourquoi il est recommandé de vérifier assez souvent la teneur en phosphate du milieu de culture si l’eau est très calcaire. On trouve des kits pour doser le phosphate dans les boutiques d’aquariophilie. En cours de culture, surtout en cas de faible croissance ou de problèmes, il est bon de mesurer la teneur en phosphate du milieu filtré et, si elle est < 5 mg/l, de rajouter du phosphate ; si on n’a pas de test phosphate on peut tenter de rajouter du phosphate pour ranimer la croissance. Dans le cas où l’eau est calcaire, la formule de milieu de culture donnée ci-dessus (formule) doit de préférence être adaptée : diminution ou suppression de l’ajout de calcium (cet ajout équivaut à 36 mg de Ca/litre dans la formule), et majoration de l’ajout de phosphate (par exemple pour chaque mg de Ca excédentaire ajouter 0,5 mg de P, soit par exemple 1,6 mg d’acide phosphorique). On peut dire que les phosphates de Ca insolubilisés constituent une réserve de Ca et de P, car ils peuvent se redissoudre en cas de besoin ; cependant cette possibilité est limitée par les boues organiques et les imperfections de l’agitation près du fond ou dans les angles du bassin. Le programme de calcul de milieu MEDFEED (voir plus loin) tient compte de ce supplément de phosphate. Il existe une alternative : ajouter 80 ppm d’EDTA comme dans le milieu Zarrouk, mais on peut répugner à ajouter une telle quantité de ce produit chélatant, 10 fois la dose contenu dans le Ferfol, d’autant que son action n’est pas garantie.

L’eau peut aussi être traitée pour diminuer sa teneur en calcium avant utilisation, ce qui complique un peu mais peut être rentable (voir Annexe 31).

Manuel de Culture Artisanale de Spiruline J.P. Jourdan | Page 19

Précautions pour le stockage de milieu de culture neuf : voir § 4.8 stockage. Précautions pour le stockage d’eau traitée : voir stockage.

4.2) Milieu « Zarrouk » (thèse Zarrouk (Paris, 1966), page 4)

Le milieu standard de Zarrouk, très souvent cité et servant de référence, mais pas très économique, est fabriqué à partir d’eau distillée et contient, en g/litre :

NaHCO3 = 16,8; K2HPO4 = 0,5; NaNO3 = 2,5; K2SO4 = 1,0; NaCl = 1,0; MgSO4 , 7 H2O = 0,2; CaCl2 = 0,04; FeSO4, 7 H2O = 0,01; EDTA= 0,08; « solution A5 » = 1,0; « solution B6 » = 1,0.

Composition de la « solution A5 », en g/l : H3BO3 = 2,86 ; MnCl2, 4 H2O = 1,81 ; ZnSO4, 7 H2O = 0,222 ; CuSO4, 5 H2O = 0,079 ; MoO3 = 0,015.

Composition de la « solution B6 », en g/l: NH4VO3 = 0,02296; K2Cr2(SO4)4, 24 H2O = 0,096; NiSO4, 7 H2O = 0,04785 ; Na2WO4, 2 H2O = 0,01794; Ti2(SO4)3 = 0,04; Co(NO3)2, 6 H2O = 0,04398.

On peut remarquer que le produit de solubilité du phosphate tricalcique est très largement dépassé dans cette formule, mais l’EDTA l’empêche de précipiter.

4.3) Et si l’on n’a aucun produit chimique ?

Dans ce cas, ou si l’on veut produire une spiruline « 100% biologique », utiliser des produits naturels. Par exemple on peut utiliser du bicarbonate de sodium naturel américain, la trona ou le natron ou de la lessive de cendres de bois, et tout le reste peut être remplacé par 4 ml d’urine (Bibliographie : Jourdan) par litre, plus le sel et, si nécessaire, du fer. Voir dans le chapitre « Nourriture » (urine) les précautions qu’implique l’utilisation d’urine. Si l’urine est proscrite pour une raison ou une autre, on a recours au nitrate du Chili et à l’acide phosphorique extrait de la poudre d’os calcinés (le phosphate naturel et le superphosphate contenant trop de cadmium) ; malheureusement le nitrate du Chili a été déclaré « non bio » en Europe malgré son origine naturelle ; alors il y a encore une possibilité : les feuilles de végétaux comestibles bon marché (exemple l’ortie) qu’on met à tremper dans la lessive carbonatée et qui apportent tous les éléments y compris du carbone, mais leur innocuité n’est pas prouvée et ils ont tendance à salir le milieu. On peut aussi utiliser les « purins de feuilles », mais leur odeur est plutôt désagréable. Ou de l’ammoniac disstillée des digestats de méthanisation bio.

A noter que l’eau de mer filtrée (à la rigueur le sel brut) est une bonne source de magnésium et apporte aussi du calcium, du potassium et du soufre.

A noter aussi la possibilité de mettre dans le milieu de culture des produits réputés insolubles mais qui en fait permettent la solubilisation progressive d’éléments consommés par la spiruline ; on peut citer la poudre d’os calcinés (apport de phosphore et calcium), le calcaire et la dolomie broyées (apport de calcium et magnésium), les boues résiduaires d’eau de cendre (apport de magnésium, calcium, soufre et oligo-éléments) et l’argile (apport d’oligo-éléments). Ces produits décanteront au fond du bassins où ils risquent d’être recouverts assez vite par des boues et perdre ainsi leur efficacité. L’agitation au balai peut aider ; mais il faut prévoir le renouvellement de ces ajouts à chaque nettoyage du bassin.

Préparation de l’eau de cendre

La cendre de bois utilisée doit être propre (blanche et sans suie) et riche en sels solubles. Les meilleurs bois sont (en Europe) ceux de peuplier, orme, tilleul, bouleau, pin, eucalyptus ; les branches sont plus riches que les troncs. En Afrique certaines parties des palmiers sont particulièrement riches en potasse

Manuel de Culture Artisanale de Spiruline J.P. Jourdan | Page 20

et servent traditionnellement à l’extraction de potasse, notamment pour la fabrication du savon (il existe d’ailleurs des fours haute température spécialement construits pour obtenir une cendre blanche à cet effet). En France existent des poêles à bois dits « Turbo » produisant une cendre blanche (voir par exemple http ://rocles03.free.fr). Pour fabriquer la lessive de cendre, on utilise par exemple le dispositif suivant : une bassine à fond percé, une couche de cailloux sur le fond, une toile, et 30 à 50 cm de cendre dans la toile ; on verse l’eau sur la cendre (environ 5 litres d’eau par kilo de cendre, et ceci plusieurs fois de suite) et on la fait percoler à travers la couche de cendre ; au début le jus coule concentré et très caustique ; s’en protéger car il attaque rapidement la peau et ne doit jamais atteindre les yeux (en cas d’atteinte, rincer immédiatement et abondamment à l’eau). On peut recycler les premiers jus. Jeter la vieille cendre quand elle est épuisée et recommencer avec de la neuve. Attendre une quinzaine de jours que la carbonatation de la lessive se fasse à l’air, dans un bassin d’environ 15 cm d’épaisseur de liquide. Pendant cette période, veiller à ce qu l’air soit renouvelé et agiter en remuant de temps en temps. Le temps de carbonatation étant inversement proportionnel à l’épaisseur, si l’on veut aller plus vite il suffit d’étaler la solution en couche plus mince ; une autre possibilité pour gagner du temps est de neutraliser avec un peu de bicarbonate de sodium (voir Annexe 13) ou de gaz carbonique concentré.

Préparation d’un milieu à base d’eau de cendre

Mesurer la salinité (voir Annexe 3) ou mieux l’alcalinité (voir Annexe 5) de l’eau de cendre carbonatée. Diluer et saler : La dilution normale est à 8 g/l de sels de cendres (ou bien alcalinité = 0,1), plus 5 g/l de sel de cuisine, mais en cas de pénurie on peut diminuer considérablement la dose de sels de cendres tout en conservant la salinité totale à 13 g/l en mettant plus de sel. Ne pas oublier de rajouter du fer. Pour mieux faire comprendre, voici un exemple donnant un milieu de culture pour 4 m², prêt à être ensemencé :
Lessiver 20 kg de cendres avec 3 fois cent litres d’eau
Carbonater la lessive à l’air quinze jours sous faible épaisseur
Diluer à densité (20°C) = 1,005 avec 300 litres d’eau
Saler avec 3 kg de sel
Ajouter les éléments manquant : 80 g de Sirop de fer, et 2 litres d’urine.
Si l’urine est impossible, la remplacer par les apports voulus en azote, phosphate, magnésium et calcium, mais qui ne seront pas toujours « bio » et pourront inclure engrais NPK et urée.

Préparation de sulfate de magnésium à partir de cendre de bois

Après avoir extrait de la cendre les sels solubles (comme on vient juste de le décrire), le gateau de filtration résiduaire peut servir à fabriquer une solution de sulfate de magnésium. Voici une recette qui a donné de bons résultats (essayée à Montpellier en Février 2006) :
- Diluer 1 kg de pâte résiduaire humide (résidu de fabrication d’eau de cendre) dans 4,5 litres d’eau.
- Ajouter progressivement de l’acide sulfurique à 32 % [Attention : manipuler l’acide avec précaution, en ayant toujours de l’eau à portée de main pour se laver immédiatement en cas de contact avec la peau] : il se dégage beaucoup de gaz carbonique, veiller à ne pas faire déborder le récipient. Arrêter l’addition d’acide quand il n’y a plus de dégagement de gaz (dans notre exemple il a fallu mettre 1,16 kg d’acide). Le pH est alors voisin de 5, mais il remonte vers 7,5 en quelques jours par fin du dégagement de gaz. Décanter et filtrer la solution obtenue, environ 6 litres,qui titre :
x 1,75 g de Mg / litre, soit en équivalent MgSO4,7 H2O : 18 g / litre
x 0,38 g de Ca / litre, sous forme de sulfate de calcium
x 0,015 g de phosphore / litre
x 2,6 g de soufre / litre

Manuel de Culture Artisanale de Spiruline J.P. Jourdan | Page 21

Le résidu est constitué en grande partie de plâtre (sulfate de calcium hydraté) sale (brunâtre). L’utilisation de cette solution comme source de Mg apporte des quantités de Ca, P et S qui peuvent généralement être négligées.
Les 6 litres de solution obtenus suffisent pour faire 1000 litres de milieu ou, utilisée en formule de nourriture, produire 10 kg de spiruline (il faut donc environ 40 g de cendres + 40 g d’acide sulfurique (compté en 100 %) par kg de spiruline).

Préparation de l’acide phosphorique à partir des os (Méthode de Jacques Falquet, décembre 2003)
- à l’acide sulfurique
Matériel :
Des os (de n’importe quel animal, même de vieux os conviennent) De quoi faire un bon feu
Un mortier
Une balance de cuisine
Une bassine ou un seau en plastique (le métal ne convient pas, sauf si il est émaillé) d’une contenance de 10 litres au moins.
De l’acide de batterie mais neuf (= acide sulfurique à 25%). Attention : ne JAMAIS prendre l’acide qui se trouve dans une batterie : utiliser uniquement de l’acide neuf, vendu en flacons.
Des récipients pour le stockage du liquide obtenu (en verre ou en plastique, le métal ne convient pas) Méthode :
Calciner fortement des os dans un feu de braises
Après refroidissement, retirer soigneusement les os (prendre le moins possible de cendres)
Réduire ces os en poudre (si les os ont été bien calcinés, ils sont blancs-gris et très faciles à broyer) Dans une bassine en plastique (et hors d’accès des enfants !) :
x | Pour 1 Kg de poudre d’os calcinés, ajouter 4 litres d’acide de batterie, remuer et laisser au
| moins deux jours (en remuant de temps en temps).
| Attention : manipuler l’acide avec précautions, en ayant toujours de l’eau à portée de
| main pour se laver immédiatement en cas de contact avec la peau.
x | Ajouter ensuite 4 litres d’eau, remuer puis laisser reposer quelques heures.
x | Prendre délicatement autant de liquide clair que possible et le garder dans un bidon de
| plastique ou dans des flacons de verre. [NDLR : nous préférons filtrer la boue blanche
| obtenue, puis la laver sur filtre avec une même quantité d’eau ; en pressant le gâteau de
| filtration, le rendement peut être alors proche de 100 % et le volume obtenu est double]

Attention ! Ce liquide (appelons-le « extrait d’os ») est corrosif : garder ce produit hors d’atteinte des enfants ou des personnes étrangères au projet. Etiquetter et inscrire un signe d’avertissement sur chaque flacon !

L’« extrait d’os » contient environ 50 grammes d’acide phosphorique par litre
Pour préparer du milieu de culture de spiruline neuf, on utilisera (en remplacement du phosphate) deux litres d’extrait d’os pour 1000 litres de milieu de culture.
Pour nourrir la spiruline après récolte, on utilisera comme source de phosphore :
1 litre d’extrait d’os par Kg de spiruline sèche récoltée.
Ceci, bien sûr, en compléments des autres produits (nitrate, etc.)
- au jus de citron
Matériel :
Des os (de n’importe quel animal, même de vieux os conviennent) et de quoi faire un bon feu. Un mortier, une balance de cuisine.
Une marmite

Manuel de Culture Artisanale de Spiruline J.P. Jourdan | Page 22

Du jus de citron
Méthode :
Calciner fortement des os dans un feu de braises
Après refroidissement, retirer soigneusement les os (prendre le moins possible de cendres) Réduire ces os en poudre (si les os ont été bien calcinés, ils sont blancs-gris et très faciles à broyer) Dans une marmite, mélanger 100 g de poudre d’os par litre de jus de citron
Faire bouillir doucement pendant 15 minutes
Laisser reposer au moins un jour, en remuant de temps en temps.
Filtrer sur une toile fine
Le liquide récupéré contient environ 20 g/l de phosphate soluble. Si nécessaire, on peut le concentrer par ébullition prolongée.
Utilisation :
Pour préparer du milieu de culture de spiruline neuf, on utilisera (en remplacement du phosphate) cinq litres de ce jus pour 1000 litres de milieu de culture.
Pour nourrir la spiruline après récolte, on utilisera comme source de phosphore :
2.5 litre de jus par Kg de spiruline sèche récoltée.
Ceci, bien sûr, en compléments des autres produits (nitrate, etc.)

(N.B. 1 : se méfier des poudres d’os calcinés vendues sur les marchés, en Afrique par exemple, dont la qualité peut être douteuse ; mieux vaut la fabriquer soi-même !)

N.B. 2 : Ces méthodes de préparation d’acide phosphorique est applicable aux phosphates de calcium naturels issus de la décomposition du guano, comme le produit dénommé PHOSMAD à Madagascar.

4.4) Renouvellement du milieu de culture/purges
Le milieu de culture doit rester peu coloré et peu trouble, aussi pauvre en matières organiques que possible, pour assurer la meilleure marche. Normalement les bactéries et le zooplancton se chargent de la minéralisation et du recyclage des déchets biologiques. Mais il arrive que la production de déchets dépasse leur élimination (surtout dans les bassins peu profonds et à productivité poussée) ; il se peut aussi que le milieu s’épuise en oligo-éléments ou que la salinité ait tendance à devenir trop élevée (en cas d’alimentation carbonée sous forme de bicarbonate de sodium ou d’alimentation en azote sous forme de nitrates par exemple), ou encore si l’eau d’appoint est très minéralisée : il faut alors remplacer le milieu de culture ou pratiquer une purge. Cette purge se fait de préférence par le fond (par pompage ou siphonnage) en éliminant en même temps des boues, ou bien lors des récoltes en ne recyclant pas le filtrat. Si les pluies font monter le niveau du bassin au point où il risque de déborder, il faut aussi pratiquer une purge pour faire baisser le niveau. Remettre dans le bassin la quantité de sels contenus dans la purge (sauf, évidemment, ceux dont on veut éventuellement abaisser la concentration). Si on a purgé parce que le niveau était trop haut à cause de la pluie, on ne remet évidemment que les sels, sans eau. Idéalement on ne devrait jamais purger.

Si un bassin s’avère trop riche en un élément (urée mise en excès par exemple) et si son niveau est suffisamment bas, on peut lui ajouter du milieu neuf privé de l’élément en trop, de manière à diluer celui-ci.

La marche sans renouvellement ni épuration du milieu de culture pendant plusieurs années est possible si les oligo-éléments sont régulièrement apportés, et si la productivité n’est pas excessive par rapport à la profondeur de culture (la profondeur exprimée en cm doit être au moins le quadruple de la productivité moyenne exprimée en g/jour/m²) et de préférence si l’agitation est maintenue la nuit pour améliorer l’oxygénation. Dans la pratique cependant un certain taux de renouvellement du milieu aide à maintenir négligeable la concentration en contaminants éventuels (chimiques ou biologiques) et à assurer l’alimentation en oligo-éléments (par les traces contenues dans l’eau d’appoint ou les sels). Il est sage de tabler au minimum sur un renouvellement tous les 2 kg de spiruline produite par m² de bassin, soit tous les 6 à 18 mois selon la productivité, en une fois ou, mieux, progressivement. Pour ne pas avoir d’ennuis, si on peut se le permettre, il vaut mieux renouveler le milieu tous les 3 mois (ou

Manuel de Culture Artisanale de Spiruline J.P. Jourdan | Page 23

purge de 1 % / jour), mais il faut savoir que ce n’est pas une nécessité et que ce n’est pas bon pour l’environnement.
N.B. a) La marche sans ou presque sans renouvellement nécessite de surveiller de plus près les contaminants possibles.
b) Le non-recyclage du jus de pressage équivaut à un taux de purge de l’ordre de 0,02 %/jour. Si la moitié de l’azote est apportée par le nitrate, celui-ci apporte à peu près l’alcalinité perdue par cette purge.
4.5) Epuration et recyclage du milieu de culture
Il est en principe recommandé, pour des raisons écologiques, de ne pas jeter le milieu purgé dans l’environnement mais soit de l’utiliser en alimentation animale ou comme engrais pour les plantes halophiles (palmiers par exemple), soit de le laisser s’évaporer à sec dans un bassin à part jouant le rôle de « marais salant », de préférence à l’abri de la pluie sous serre. Les sels récupérés, semblables au natron naturel, peuvent certainement être purifiés par calcination à haute température (attention au bon réglage de la température et de l’apport d’air, pour éviter le noircissement par charbonnement) ou par recristallisation, puis recyclés, mais ceci reste à essayer. Avec l’évaporation à sec, un renouvellement tous les 3 mois nécessiterait une surface d’évaporation d’un tiers de la surface des bassins.

Il est aussi possible de recycler le milieu de culture après épuration partielle (procédé utilisé par F. Haldemann en Equateur : voir sa publication au Colloque des Embiez, mai 2004, page 86) : on s’affranchit dans ce cas de la relation du § 4.4 ci-dessus (profondeur = 4 x productivité) ; cette épuration consiste en une combinaison de filtration, décantation et traitement biologique anaérobie puis aérobie par la flore naturelle, à l’abri de la lumière, dans des bassins profonds de 1 à 2 m. avec un temps de séjour global de 2 à 4 semaines. Autre façon de procéder, moins bon : envoyer les purges dans un bassin « naturel » peu ou pas agité, de surface égale au tiers de celle des bassins actifs et profond de 2 m., récupérer pour l’alimentation animale les (très belles) spirulines qui s’y développent en surface et recycler le milieu après stérilisation éventuelle (en cas de contamination par des microorganismes étrangers) par les U.V. ou par chauffage. Un simple stockage du milieu de culture pendant 6 mois à 20°C, sans agitation et à l’abri de la lumière, le purifie assez bien : en zone tempérée, par exemple, le milieu de culture se purifie de lui-même nettement pendant l’hiver où la production est nulle, et ceci malgré la basse température.

Un autre procédé d’épuration est en cours de développement en 2013/14, déjà utilisé chez Peter Schilling aux Canaries : par skimming (écumage).Il extrait un concentrat fortement coloré contenant protéines et EPS et fournit un milieu recyclé très propre. Il est prévu de le stériliser avant recyclage, afin d’éliminer les cyanobactéries étrangères et les plus petites spirulines pour éviter les contamination et les dérives de la souche. L’utilisation de ce procédé est très vivement recommandé.

Plutôt que de construire une installation de purification, il parait plus simple, au niveau artisanal, de majorer la surface et/ou la profondeur des bassins pour y réaliser l’épuration biologique « in situ », tout en assurant le maintien du pH par le CO2 atmosphérique, au prix d’une productivité plus basse, mais avec un taux de purge du milieu très faible, voire nul. Une stérilisation annuelle est recommandée.

Autre solution possible : utilisation des purges comme engrais par épandage agricole ou sur tas de compost. La forte concentration du milieu de culture en sodium est gênante pour de nombreuses plantes, mais pas pour toutes (par exemple pas pour le palmier cocotier). On peut aussi remplacer dans la formule du milieu de culture le maximum d’ions sodium par des ions potassium. L’eau de cendre (http://milieu.htm/) (assez concentrée en potasse pour ne pas nécessiter plus de deux ou trois grammes de sel par litre) convient. Sinon on peut utiliser un milieu contenant 10 g de bicarbonate de potassium + 2 g de nitrate de potassium + 1 g de sulfate dipotassique + 3 g de sel par litre (le reste comme au § 4.1). Pour obtenir un milieu à pH proche de 10, on pourra remplacer les 10 g de bicarbonate de potassium par 6 g de bicarbonate de potassium + 2 g de potasse caustique (attention : mêmes précautions de sécurité qu’avec la soude !) ou bien par 3 g de bicarbonate de potassium + 4 g de carbonate de potassium. Un milieu riche en potassium est au moins deux fois plus cher qu’un milieu riche en sodium, mais il a l’avantage supplémentaire de donner une spiruline qui peut être utile pour certains régimes « sans sodium » ; cet avantage pourrait plus que compenser le surcoût du milieu.
4.6) Utilisation de l’eau de mer

Utiliser l’eau de mer pour établir et maintenir une culture de spiruline, sans traitement préalable de l’eau de mer autre qu’une filtration, est possible mais à condition de travailler à un pH régulé avec une

Manuel de Culture Artisanale de Spiruline J.P. Jourdan | Page 24

grande précision au voisinage de celui de l’eau de mer, ce qui est techniquement difficile pour les producteurs artisanaux. L’eau de mer contient une quantité excessive de calcium et de magnésium qui, aux pH élevés, provoquent une précipitation abondante de carbonates et phosphates. D’autre part la salinité élevée de cette eau (35 g/l) interdit son emploi comme eau d’appoint pour compenser l’évaporation, sauf si celle-ci est maintenue très faible par utilisation judicieuse de bassins sous serre.

Ripley Fox a développé le concept d’une ferme de spiruline (géante) fonctionnant à l’eau de mer traitée au carbonate de soude, lui-même produit sur place à partir de soude électrolytique. Le chlore et l’hydrogène sous-produits de l’électrolyse sont transformés en acide chlorhydrique utilisé pour générer du CO2 pur à partir de carbonate de soude. Le problème de la compensation de l’évaporation est réglé en rejetant à la mer le milieu de culture (préalablement neutralisé) lorsque sa salinité est devenue trop élevée. Ce concept sera peut-être appliqué un jour, mais il demande de gros moyens, hors de portée d’un petit producteur. De plus il nécessite une véritable usine chimique qui ne plairait pas à certains.

Par contre l’eau de mer peut être utilisée avec profit, en petites quantités, pour apporter magnésium et soufre. Et l’eau de mer dessalée est déjà largement utilisée pour produire la spiruline (Canaries p. ex.).

4.7) pH optimum

Le pH optimum d’un milieu de culture neuf à confectionner dépend de son utilisation.
S’il doit être inséminé pour démarrer une nouvelle culture, son pH doit être d’au moins 9, le plus proche possible de celui de la souche utiliée : s’il est trop bas la culture risque de mal démarrer, avec formation de grumeaux ou précipitation de la spiruline au fond. Le natron ou le mélange carbonate + bicarbonate de sodium, ou l’eau de cendre carbonatée sont donc bien adaptés à ce cas.

Par contre si le milieu neuf doit servir d’appoint à une culture existante son pH peut être avantageusement voisin de 8, ce qui contribue à maintenir le pH de la culture suffisamment bas par apport de bicarbonate de sodium. C’est typiquement le cas des bassins en cours d’extension (« à géométrie (http://semis.htm/) variable »). Dans ce cas le milieu doit être à base de bicarbonate de sodium seul, si ce dernier est disponible. Si le milieu est à bas pH on pourra plus facilement utiliser du NPK non désammonié sans risquer de tuer la spiruline, car ce qui est dangereux c’est NH3 (à bas pH c’est NH4 qui domine).

4.8) Stockage de milieu de culture neuf et d’eau traitée

Il n’est pas recommandé de stocker du milieu de culture neuf, même à l’abri de la lumière, car il constitue par nature un « bouillon de culture » où pourrait se développer des micro-organismes indésirables. Cette remarque s’applique surtout aux milieux à bas pH.

Il est également fortement déconseillé de stocker de l’eau douce, par exemple de l’eau traitée pour éliminer l’excédant de dureté, en présence de lumière car en quelques jours s’y développeraient des algues étrangères et des cyanobactéries. Or parmi ces dernières il en est de hautement toxiques (cas de certains lacs d’eau douce).

4.9) Logiciels de calcul « MILIEU »

Pour faciliter le calcul des milieux et de la nourriture minérale en tenant compte des matières premières et de l’analyse de l’eau disponibles des programmes de calcul ont été rédigés (Calculs).

5) ENSEMENCEMENT
5.1) Quelle souche de spiruline utiliser ?

Manuel de Culture Artisanale de Spiruline J.P. Jourdan | Page 25

Il existe des spirulines de « races » (souches) différentes, bien qu’elles aient toutes des caractères communs qui les distinguent des autres cyanobactéries. On reconnaît très vite au microscope ou même à la loupe de fort grossissement (25 fois) si les spirulines sont spiralées ou droites mais il est moins facile de dire de quelle souche il s’agit car les spirulines ont une forte tendance à changer de taille et de forme (spiralée plus ou moins serrée ou « ondulée » ou droite). En présence de formes droites il existe un doute : s’agit-il de spirulines ou d’Oscillatoria semblables aux spirulines droites et dont certaines sont toxiques ? Un œil exercé ne peut confondre une droite avec une des Oscillatorias toxiques courantes (Cyanobactériess étrangères). Un trop fort pourcentage de droites conduit à des difficultés de récolte. Donc prendre de préférence une semence 100 % spiralée, de grande taille, d’un beau vert tirant vers le bleu-vert, filtrant facilement. On pouvait se procurer des souches pures à l’Institut Pasteur chez qui la « Lonar » s’appelle PCC 8005, mais Pasteur n’offre plus ce service. Presque toutes nos souches sont en fait des « Arthrospira platensis » selon la dénomination scientifique. Nous appelons « spiralées type Lonar » les souches dont les filaments sont en « queue de cochon », telle la « Lonar ». Nous appelons « spiralées ondulées » (ou « ondulées » tout court) les souches dont les filaments sont en spirale étirée, telle la « Paracas ». Pour faciliter le choix de la souche, voici quelques éléments utiles :

- Les spiralées type Lonar flottent en général plus que les ondulées et les droites, ce qui permet éventuellement leur séparation.
- Les spiralées filtrent mieux et leur biomasse fait la boule facilement sur le filtre, du moins lorsque le milieu de culture est assez pur.
- Les spiralées ont plus tendance à former des peaux et grumeaux verts flottants, surtout à pH bas et en l’absence d’ammonium (voir § 7.9), ce qui est un inconvénient.
- La teneur en matière sèche dans la biomasse essorée prête au séchage est plus élevée chez les ondulées et les droites que chez les spiralées type Lonar, ce qui est un avantage.
- La biomasse des spiralées type Lonar sèche plus facilement.
- Les ondulées n’ont pratiquement pas tendance à devenir droites, du moins dans les conditions d’exploitation normales.
- Les ondulées résistent au pompage par pompe centrifuge, alors que les spiralées se cassent.
- Les ondulées résistent mieux au choc osmotique (on peut parfois laver la biomasse avec de l’eau douce sans que les cellules n’éclatent, alors qu’avec les ondulées c’est rare).

Il n’y a pas de différences de composition ou de valeur nutritionnelle notables entre ces souches, par contre la couleur verte des ondulées est plus sombre ; certains préfèrent la couleur et la saveur de l’une ou l’autre souche, mais ceci est affaire de goût personnel.

Les ondulées et les droites ont des caractères communs, mais les ondulées ne souffrent pas de la suspicion de ne pas être de « vraies » spirulines.

Au total, notre préférence pratique va aux « ondulées », bien que les « spiralées » soient plus belles d’aspect au microscope.

5.2) Ensemencement à partir d’une quantité importante de semence

Pour ensemencer il suffit de transvaser dans du milieu de culture neuf un certain volume de culture provenant d’un autre bassin en production jusqu’à ce que la couleur devienne verte (le « disque de Secchi » ne doit plus se voir à 5 cm de la surface). On ensemence de préférence le soir. On peut réduire le volume à transférer en prélevant du surnageant concentré ou encore en récoltant de la spiruline sans l’essorer (bien la disperser dans un peu de milieu de culture

Manuel de Culture Artisanale de Spiruline J.P. Jourdan | Page 26

avant de la verser dans le bassin, ceci pour éviter de laisser des grumeaux, ce qui n’est pas facile avec les souches spiralées : utiliser par exemple une hélice de mélangeur de peintures branchée sur une perceuse).

Pour réussir le démarrage d’une culture, on a toujours intérêt à démarrer aussi concentré que possible en spiruline. C’est pourquoi on démarre avec le niveau minimum de liquide (par exemple 5 à 10 cm) si la disponibilité de semence est limitée, et/ou on utilise la technique du « bassin à géométrie variable ». Une culture ensemencée concentrée (Secchi < 3 par exemple) risque beaucoup moins d’être envahie par les chlorelles ou de souffrir de l’entraînement de spirulines dans les boues calcaires (quand on travaille avec une eau dure).

Si la culture commençante est trop diluée (« Secchi » supérieur à 5 cm), il faut ombrer, sinon on risque la mort des spirulines par photoxydation au soleil. Il faut aussi veiller à éviter les dépôts minéraux qui entraînent avec eux des spirulines (pour cela filtrer au besoin le milieu neuf avant de l’ensemencer et maintenir l’agitation pendant la nuit si possible). Si le niveau initial est le niveau normal, et si le milieu neuf est à base de bicarbonate de sodium, ne pas ensemencer trop concentré non plus, sinon il faudra récolter avant que le pH ait atteint le niveau minimum de 9,6 recommandé (voir § 7.13) ; mais il est facile de démarrer avec un milieu de culture à pH 9,6 ou plus en mélangeant au bicarbonate de sodium du carbonate de sodium ou de la soude (voir Annexe 12 et Annexe 13). Un autre avantage d’un pH initial élevé est la réduction de la tendance initiale à la formation de grumeaux avec les souches spiralées, avantage pouvant être décisif quand on a peu de semence : il ne faut pas en perdre en grumeaux ! D’autre part il est certain qu’il y a intérêt à ne pas soumettre la semence de spiruline à un choc de pH : il nous est arrivé de voir mourir une culture débutante suite à un choc de pH de 2 unités (de 10 à 8) : notre recommandation est de limiter le delta Ph à 1 unité.

Il est permis de stocker quelques jours et transporter une semence très concentrée (3 à 4 g/l par exemple, pas plus), à condition de l’agiter et de l’aérer au moins de temps à autre sinon elle fermente et sent mauvais. A 2 g/l, le transport peut durer dix jours. A noter qu’une couche flottante prélevée avec soin peut titrer 5 à 10 g/l. Dans une semence très concentrée le pH baisse et une odeur mercaptée (odeur de « choucroute ») se développe au cours du temps. Après l’ensemencement avec une spiruline ayant « souffert » au stockage, le nouveau bassin peut mousser excessivement, mais cela disparaît normalement en un à deux jours.

La semence se conserve mieux à basse température, vers 10°C par exemple (réduction de la respiration). La biomasse fraîche, même pressée, peut servir à ensemencer un bassin. C’est important pour faciliter le transport sous forme concentrée et pour ensemencer immédiatement un grand volume. Faire le transport à froid autant que possible, et en limiter la durée. Diluer progressivement la semence concentrée, en l’homogénéisant : il ne doit pas rester de grumeaux (passer le mélange sur tamis pour éliminer les éventuels grumeaux restant).

5.3) A partir d’une petite quantité de semence

Pour implanter une culture de spiruline dans un site qui en est dépourvu, ou pour redémarrer avec une nouvelle souche, il n’est généralement pas possible de disposer d’une grande quantité de culture pour ensemencer. Fréquemment on ne dispose que d’un flacon rempli à moitié seulement (pour maintenir assez d’oxygène). Si on réussit à se procurer une souche pure, on n’aura probablement que quelques millilitres de culture au départ (N.B. le milieu de culture indiqué par l’Institut Pasteur dans sa documentation accompagnant ses souches

Manuel de Culture Artisanale de Spiruline J.P. Jourdan | Page 27

correspondait au maintien des souches et il diffère du milieu de culture pour la croissance). On peut aussi partir d’un seul filament qu’on isole soi-même (voir § 5.6).
Supposons que le point de départ soit 150 g de culture à 1 g/l de concentration en spiruline et que l’objectif soit de multiplier le volume de semence initial pour ensemencer un bassin de 1000 litres. Il va falloir faire au moins 4 cultures successives, en multipliant chaque fois le volume par 5, ce qui demande environ trois semaines au total (avec un taux de croissance de 35 %/jour, possible avec du milieu de culture à base de bicarbonate de sodium). La première mini-culture se fera dans un bocal de deux litres, la seconde dans une bassine de 10 litres, la troisième dans une bassine de 50 litres, la dernière dans un mini bassin provisoire en film plastique de 1 m² (ou plusieurs grandes bassines).

Si la concentration initiale de chaque culture est plus faible que Secchi = 5 cm, il faut non seulement ombrer mais agiter jour et nuit (sinon les spirulines peuvent s’agglomérer, notamment sur les bords, et ne plus pouvoir se disperser ensuite). Il est possible d’éviter cette agglomération en relevant le pH, mais cela risque d’augmente les boues minérales qui peuvent piéger les spirulines. Moyennant quoi on arrive quand même à démarrer une culture en partant de très faibles concentrations (Secchi = 15).

L’agitation continue des cultures en petits récipients (bouteilles, seaux, bassines par exemple) se fait au moyen d’un petit bullage d’air comme dans un aquarium et nécessite un rapport hauteur de liquide/diamètre élevé, égal ou supérieur à 1, avec si possible un fond conique, le tube d’amenée d’air débouchant tout près du fond (il existe des compresseurs d’aquarium fonctionnant sur pile électrique). Il est pratique de chauffer et éclairer simultanément les petites cultures initiales en laboratoire par des lampes à incandescence ou halogène placées à la bonne distance pour maintenir automatiquement environ 35°C dans la culture (ne pas éclairer plus de 16 hr/jour).

L’agitation de volumes importants (> 100 litres) de cultures diluées peut se faire au moyen d’une petite pompe d’aquarium, mais on a intérêt à ne pomper que par intermittance pour ne pas abîmer les spirulines, surtout les Lonar,, donc à utiliser un programmateur à horloge. Les souches ondulées sont beaucoup moins sensibles aux dégats des pompes.

Pour éviter la formation de grumeaux (surtout avec les souches spiralées type Lonar et s’il n’y a pas d’agitation continue) au début de l’ensemencement, il faut diluer très progressivement la semence concentrée, en ajoutant des petites doses de milieu de culture neuf à base d’urée, par exemple à chaque agitation, en gardant une concentration élevée en spirulines les deux premiers jours. On a ensuite intérêt à conserver une concentration en spiruline élevée (0,3 g/l ou plus) et donc à diluer le moins possible la culture à chaque augmentation de volume : une dilution progressive (par exemple quotidienne) est la meilleure. On peut pour cela utiliser un « bassin à géométrie variable », extensible en surface, facile à réaliser avec du film plastique. Chaque augmentation de volume (donc surface) se fait par dilution à l’aide de milieu de culture neuf (de préférence à base de bicarbonate de sodium). Le milieu neuf de dilution – s’il est à base d’urée comme source d’azote – doit comporter une forte dose d’urée (0,04 g/l) ou, s’il est à base d’urine : 6 ml d’urine/l. Si le milieu neuf est à base de bicarbonate de sodium, donc de pH = 8, le pH de la culture se maintient autour de 9,6 pendant sa phase d’extension. Ce pH peut ne pas être suffisant pour éviter les grumeaux de spiralées : dans ce cas relever le pH en ajoutant du milieu à base de carbonate jusqu’à pH = 10,3. On accélère la croissance pendant la phase « bassin à géométrie variable » en maintenant la profondeur faible (5-10 cm).

Manuel de Culture Artisanale de Spiruline J.P. Jourdan | Page 28

N.B. :
1) Une culture peut mourir suite à une dilution, un éclairage ou un chauffage trop forts ou un excès d’urée.
2) L’augmentation de niveau d’un bassin doit se faire par ajout de milieu de culture. L’ajout directement dans le bassin des sels non dissous peut être très dangereux pour la culture.
3) Si on prépare d’avance une réserve de milieu de culture de dilution, la garder peu de temps et fermée et à l’obscurité pour qu’elle ne risque pas de se contaminer par des algues étrangères.
4) Attention : un choc de pH de 2 unités est souvent mortel : lors des ensemencements veillez à minimiser les différences de pH entre semence et bassin.
5.4) Taux de croissance initial

La vitesse de croissance dépend de plusieurs facteurs dont le pH. Elle est maximum à pH inférieur à 10, donc on a intérêt à utiliser du bicarbonate de sodium pour démarrer rapidement une nouvelle culture. On a aussi intérêt à maximiser la surface de culture (donc bassin peu profond si possible). La méthode d’extension progressive de la surface de bassin (« à géométrie variable ») décrite au § précédent favorise une croissance rapide. On caractérise au mieux la rapidité d’implantation d’une nouvelle culture en calculant le taux de croissance dans la phase initiale de croissance qui précède la phase des récoltes. Ce taux s’exprime en % de croissance en poids par jour poids exprimé en sec). Dans des conditions favorables, en milieu à base de bicarbonate de sodium, il peut dépasser 30%/jour. A partir d’un gramme de semence (exprimé en spiruline sèche), un taux de 20%/jour permet d’obtenir 20 m² de bassin de 15 cm de profondeur prête à la récolte en 40 jours, ou 120 m² en 50 jours.

N.B. On serait tenté d’éclairer les cultures 24 heures par jour pour augmenter le taux de croissance, mais il vaut mieux ne pas soumettre les spirulines à plus de 16 heures d’éclairement par jour, même si l’on dispose d’éclairage artificiel.

5.5) Réserve de semence

En temps normal les bassins eux-mêmes servent de réserve s’ils restent en bonne santé et sans contaminant, mais il faut prévoir les accidents et comment passer la mauvaise saison éventuelle. On a aussi intérêt, quand on le peut, à vidanger complètement les bassins et à les redémarrer à zéro pour assurer le maintien d’une bonne qualité de spiruline (sans contaminant, sans droites, filtrant bien). Pour cela il faut disposer de semence pure. Il est donc recommandé de conserver un peu de souche pure « en laboratoire » (= dans la maison), à température modérée ou ambiante, sous faible éclairage environ 12 heures/jour (en l’absence totale de lumière la spiruline meurt en quelques jours, par exemple en 2 jours à 35°C), légèrement agitée, et renouvelée (« repiquée ») tous les 2 ou 3 mois : dans ces conditions, elle se conserve bien alors qu’en culture trop intensive elle a tendance à muter et peut dégénérer. Une bouteille en plastique convient très bien comme récipient. Pour agiter et aérer, le plus pratique est un petit compresseur d’air électrique pour aquarium, qu’on peut ne faire marcher que de temps en temps grâce à un programmateur (il existe de tels compresseurs et programmateurs fonctionnant sur courant continu). Pour à la fois éclairer et chauffer la culture il suffit d’une lampe de chevet de 40 Watt dirigée horizontalement vers la bouteille, à la distance donnant une température correcte (< 30°C). Pour conserver des quantités plus importantes de semence, on utilise des bassines ou aquariums, avec des lampes plus puissantes, à incandescence ou halogènes ; les tubes luminescents chauffent peu et

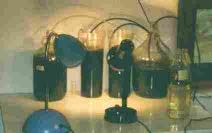
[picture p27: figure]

Manuel de Culture Artisanale de Spiruline J.P. Jourdan | Page 29

conviennent si la température ambiante est suffisamment élevée. Photo d’une réserve de semence :

5.6) Sélection et culture monoclonale

L’ensemencement à partir de n’importe quelle semence donne une culture ayant les mêmes contaminants éventuels que la semence. Pour être sûr d’avoir une culture pure
(« monoclonale »), il faut théoriquement partir d’un seul filament sélectionné et lavé avec du milieu stérile.

Il est possible de séparer un filament individuel à partir d’un mélange de souches. Diverses techniques, basées sur une dilution de la culture d’origine, sont utilisables pour effectuer cette séparation, qui reste une opération difficile pour un non-spécialiste.

Il est plus facile et rapide de prélever dans une culture très peu contaminée (par des spirulines droites par exemple) une goutte sans contaminant : la sélection se fait par examen au microscope à faible grossissement, en rejetant les gouttes contaminées ne serait-ce que par un seul filament étranger et en mettant les gouttes pures dans du milieu de culture filtré (en rinçant la lame de microscope à la pissette remplie de milieu de culture filtré). On collecte autant de « gouttes » pures que l’on peut dans le temps disponible : plus il y en aura, plus vite on obtiendra une semence utilisable. Il est prudent de faire cette opération de sélection régulièrement pour maintenir ainsi un stock pur de sécurité sans attendre qu’un % de contaminants (droites par exemple) trop élevé rende l’opération de sélection difficile.

5.7) Dérive d’une culture vers une autre souche

Il est fréquent d’assister en cours de culture à une variation de forme et/ou de taille des filaments de spiruline. Vers la forme droite bien sûr mais aussi vers d’autres formes spiralées, notamment vers des formes plus petites ou resserrrées qui passent préférentiellement dans le filtrat. Il serait illusoire de chercher à contrer cette dérive par l’utilisation de toiles de filtration à maille plus fine (ce qui ne fait en général que ralentir l’évolution). La seule parade radicale, en dehors de la purge, est le non recyclage direct des filtrats : le recyclage doit se faire à travers le système d’épuration (Epuration).

Manuel de Culture Artisanale de Spiruline J.P. Jourdan | Page 30
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

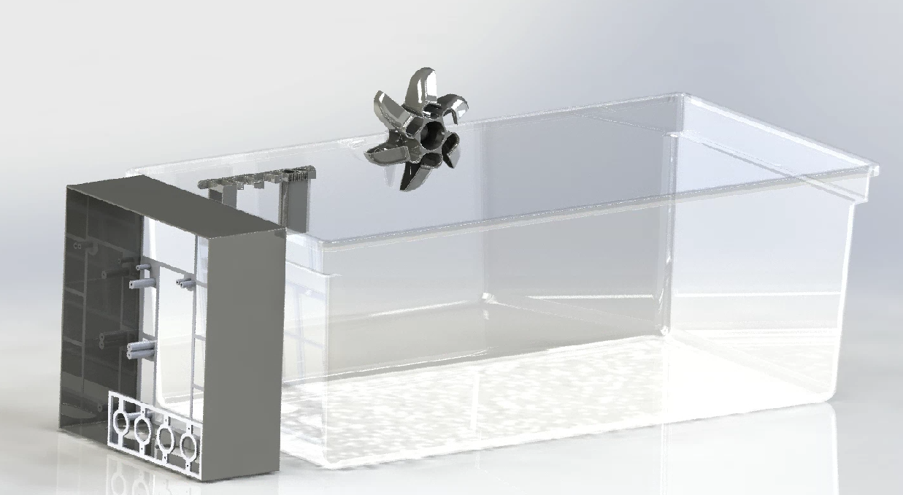
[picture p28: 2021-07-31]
docs/progression medias/setup.png

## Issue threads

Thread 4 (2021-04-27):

Culture medium

ninicksicard, 2021-04-27:
1kg/100L sodium bicarbonate
0.5kg/100L sea salt

Let rest for 12h

2 liters of water
0.2kg of Potassium Nitrate
0.02 kg of Monoammonium Phosphate
0.002 kg of Iron Sulphate
0.01 kg of Potassium Sulphate
0.01 kg of Magnesium Sulphate
2L/100L

https://www.google.com/amp/s/www.instructables.com/Homemade-Organic-Spirulina-Culture/%3famp_page=true

K 19
N 7
P 15

Potassium nitrite
K =19
N = 7

Monoamonium phosphate (NH4)H2PO4
N=7
P=15

Potassium sulfate
K2SO4

K=38

Closed 2021-05-05.

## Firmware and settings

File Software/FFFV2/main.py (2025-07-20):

"""Entry point and runtime logic for the example device controller."""

from ESP32S3_IO_MAPPING import *
# Import print_control so the custom print replacement is active
try:
    from print_control import custom_print as print #noqa: F401
    from print_control import set_print_enabled 
except Exception:
    pass
import time
from machine import Pin, PWM, Timer
from MOTOR import MOTORDriver
import wifi_manager
import MYmqtt
import json
import sys


mqttclient = None
wait_timer = None
mqtt_connect_timer = None
retry_timer = None
main_timer = None
wait_count = 0

motor_PIN_A = AO0
motor_PIN_B = AO1
LED_PIN = DO4
LED = None
BUTTON_PIN = DI3

# Initialize the servo motor (PWM) and potentiometers (ADC)
motor = None

# MQTT topic for receiving new loop data
MQTT_LOOP_TOPIC = 'home/template/device/loop'


BUTTON = None
last_button_ms = 0
DEBOUNCE_MS = 200

# Create MQTT client
# will be initialized in run()

# Function to set motor state via MQTT
def mqtt_set_state(self, state: str, *args):
    """Handle MQTT command to set the motor state."""
    print(f"mqtt_set_state received {type(state)} instead. state:{state}, args:{args}")
    _state = state in sys.modules[__name__].mqttclient.ON
    sys.modules[__name__].set_state(_state)
    sys.modules[__name__].set_standby(not _state)





def run():
    """Initialise hardware, connect to Wi-Fi and enter the main loop."""

    try:
        print_control.set_print_enabled(True)
    except Exception:
        pass
    print("booting")
    time.sleep(1)

    sys.modules[__name__].LED = Pin(LED_PIN, Pin.OUT)
    sys.modules[__name__].motor = MOTORDriver(pwm_pin_A=motor_PIN_A, pwm_pin_B=motor_PIN_B)
    
    # Main loop for motor sequence playback and MQTT message checking
    def loop_play_sequence():
        """Advance the current motor sequence."""
        sys.modules[__name__].motor.play_sequence()
    sys.modules[__name__].loop_play_sequence = loop_play_sequence
    
    # Function to toggle motor state
    def toggle_state(*args):
        """Callback to toggle the motor state."""
        global last_button_ms
        now = time.ticks_ms()
        if time.ticks_diff(now, last_button_ms) < DEBOUNCE_MS:
            return
        last_button_ms = now
        print(f"toggle_state received args:{args}")
        sys.modules[__name__].motor.toggle_state()
        set_standby(not sys.modules[__name__].motor.state)
    sys.modules[__name__].toggle_state = toggle_state

    # Function to set motor state
    def set_state(state: bool, *args):
        """Set the motor ``state`` and update the LED."""
        print(f"set_state received {type(state)}, state:{state}, args:{args}")
        sys.modules[__name__].motor.set_state(state)
        print(f"set_state - motor.state : {motor.state}")
        sys.modules[__name__].LED.value(sys.modules[__name__].motor.state)
    sys.modules[__name__].set_state = set_state

    # Function to set standby mode
    def set_standby(standby: bool, *args):
        """Enable or disable standby mode."""
        print(f"set_standby received {type(standby)} instead. standby:{standby}, args:{args}")
        sys.modules[__name__].motor.set_standby(standby)
        print(f"set_standby - motor.standby : {motor.standby}")
        # Function to handle receiving new loop data via MQTT
    sys.modules[__name__].set_standby = set_standby
        
    def mqtt_receive_loop(topic, message):
        """Receive a new motion sequence via MQTT."""
        print(f"Received loop data on topic {topic}: {message}")
        try:
            # Parse the received message as JSON
            new_loop = json.loads(message)
            
            # Validate the structure of the loop data
            if isinstance(new_loop, list) and all(
                isinstance(item, list) and len(item) == 2 and isinstance(item[0], (int, float)) and isinstance(item[1], int)
                for item in new_loop
            ):
                sys.modules[__name__].motor.save_loop_to_file(new_loop)  # Save the new loop to the file
                sys.modules[__name__].motor.loop = sys.modules[__name__].motor.load_loop_from_file() or sys.modules[__name__].motor.loop  # Reload the loop
                print("New loop data successfully updated and reloaded.")
            else:
                print("Invalid loop format received.")
        except Exception as e:
            print(f"Error processing loop data: {e}")
    sys.modules[__name__].mqtt_receive_loop = mqtt_receive_loop
            
    sys.modules[__name__].BUTTON = Pin(BUTTON_PIN, Pin.IN, pull=Pin.PULL_UP)
    sys.modules[__name__].BUTTON.irq(trigger=Pin.IRQ_RISING, handler=sys.modules[__name__].toggle_state)

    sys.modules[__name__].mqttclient = MYmqtt.myMQTT()

    sys.modules[__name__].mqttclient.topics.update({
        MYmqtt.Topic('home/template/device'): [mqtt_set_state, None],
        MYmqtt.Topic(MQTT_LOOP_TOPIC): [mqtt_receive_loop, None],
    })


    sys.modules[__name__].wifi_manager.setup()

    sys.modules[__name__].mqttclient.reconnect = True
    sys.modules[__name__].wait_count = 0

    def _check_wifi(timer):
        if wifi_manager.WifiManager.connected:
            timer.deinit()
            sys.modules[__name__].mqttclient.connect_mqtt()
            sys.modules[__name__].wait_timer.init(period=1000, mode=Timer.PERIODIC, callback=sys.modules[__name__]._wait_mqtt)
        else:
            print("wait_wifi")
    sys.modules[__name__]._check_wifi = _check_wifi
    
    
    def _wait_mqtt(timer):

        if sys.modules[__name__].mqttclient.client:
            timer.deinit()
            sys.modules[__name__].wait_count = 0
            sys.modules[__name__].mqttclient.subscribe()
        else:
            sys.modules[__name__].wait_count += 1
            print(".")
            if sys.modules[__name__].wait_count >= 30:
                print("MQTT connection timed out")
                timer.deinit()
                def _restart(t):
                    sys.modules[__name__].mqtt_connect_timer = Timer(3)
                    sys.modules[__name__].mqtt_connect_timer.init(period=5000, mode=Timer.PERIODIC, callback=sys.modules[__name__]._check_wifi)
                sys.modules[__name__].retry_timer = Timer(4)
                sys.modules[__name__].retry_timer.init(period=5000, mode=Timer.ONE_SHOT, callback=sys.modules[__name__]._restart)
    sys.modules[__name__]._wait_mqtt = _wait_mqtt
    
    
    def _main_loop(timer):
        if sys.modules[__name__].mqttclient.client:
            sys.modules[__name__].mqttclient.heartbeat()
            sys.modules[__name__].mqttclient.check_msg()
        sys.modules[__name__].loop_play_sequence()
        
    sys.modules[__name__]._main_loop = _main_loop
    
    
    sys.modules[__name__].main_timer = Timer(5)
    sys.modules[__name__].main_timer.init(period=100, mode=Timer.PERIODIC, callback=sys.modules[__name__]._main_loop)

    sys.modules[__name__].wait_timer = Timer(6)

    sys.modules[__name__].mqtt_connect_timer = Timer(7)
    sys.modules[__name__].mqtt_connect_timer.init(period=1000, mode=Timer.PERIODIC, callback=sys.modules[__name__]._check_wifi)

    # Keep function alive; actual loop handled by timers

if __name__ == "__main__":
    run()

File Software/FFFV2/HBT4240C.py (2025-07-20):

from ESP32S3_IO_MAPPING import *
from machine import Pin, Timer, PWM
import time
import json

class StepperMotor:
    def __init__(self, step_pin, dir_pin, enable_pin, alarm_pin, limit_min_pin, limit_max_pin, steps_per_revolution=200):
        self.step = Pin(step_pin, Pin.OUT)
        self.direction = Pin(dir_pin, Pin.OUT)
        self.enable = Pin(enable_pin, Pin.OUT)
        self.alarm = Pin(alarm_pin, Pin.IN, pull=Pin.PULL_DOWN)
        self.limit_min = Pin(limit_min_pin, Pin.IN, pull=Pin.PULL_UP)
        self.limit_min_debounce = self.limit_min.value()
        
        self.limit_max = Pin(limit_max_pin, Pin.IN, pull=Pin.PULL_UP)
        self.limit_max_debounce = self.limit_max.value()
        self.steps_per_revolution = steps_per_revolution
        
        self.position_saved = 1
        
        self.max_position = 0 
        self.position = 0  # Current position in pulses
        self.speed = 0  # Current speed in pulses/sec
        self.acceleration = 0  # Acceleration in pulses/sec^2
        self.target_speed = 0  # Target speed in pulses/sec
        self._load_params()
        
        
        self.target_position = self.position  # Target position in pulses
        self.last_step_time = time.ticks_us()  # Last step timestamp

        # Timer for asynchronous control
        self.timer = Timer(10)
        self.timer.init(period=10, mode=Timer.PERIODIC, callback=self._update)
        self.timer_active = True

        # Initialize the motor as disabled
        self.enable.value(1)
        self.step_interval = 0
        self.steps_to_do = 0

    def set_direction(self, clockwise):
        self.direction.value(1 if clockwise else 0)

    def enable_motor(self, enable):
        self.enable.value(0 if enable else 1)

    def do_step(self):
        current_time = time.ticks_us()
        self.step_interval = int(1_000_000 / self.target_speed) if self.target_speed > 0 else 0

        if self.step_interval != 0:
            time_elapsed = time.ticks_diff(current_time, self.last_step_time)

            if time_elapsed >= self.step_interval:
                self.steps_to_do = min(int(time_elapsed // self.step_interval), int(abs(self.target_position - self.position)))

                for _ in range(self.steps_to_do):
                    self.step.value(1)
                    time.sleep_us(2)  # Pulse width
                    self.step.value(0)
                    time.sleep_us(2)

                self.position += (1 if self.direction.value() == 1 else -1) * self.steps_to_do
                
                self.last_step_time = time.ticks_us()

    def set_speed(self, speed):
        self.target_speed = speed

    def set_acceleration(self, acceleration):
        self.acceleration = acceleration

    def move_to(self, target_position):
        self.target_position = target_position

    def stop(self):
        self.target_position = self.position


    def _update(self, timer):
        if self.limit_min.value() == 0:
            if self.limit_min_debounce != 0:        
                #print("min_limit_switch")
                pass
            if self.position != 0:
                self.position = -20
                self.target_position = 0

        if self.limit_max.value() == 0:
            if self.limit_max_debounce != 0:        
                #print("max_limit_switch")
                pass
            if self.position != self.max_position:
                self.max_position = self.position-20
                self.target_position = self.max_position

        if self.target_position is not None:
            error = self.target_position - self.position

            direction = 1 if error > 0 else -1
            self.set_direction(clockwise=(direction > 0))

            if abs(error) > 0:
                self.do_step()
                self.position_saved = 0
            else:
                #if not self.position_saved :
                    #self._save_position()  # Persist position
                    #self.position_saved = 1
                    
                self.last_step_time = time.ticks_us()
        self.limit_min_debounce = self.limit_min.value()
        self.limit_max_debounce = self.limit_max.value()

#     def _save_position(self):
#         with open("stepper_position.json", "w") as f:
#             json.dump({"position": self.position, "max_position": self.max_position, "target_speed": self.target_speed, "speed": self.speed, "acceleration": self.acceleration}, f)
#         
    def _load_params(self):
        
        try:
            with open("stepper_position.json", "r") as f:
                data = json.load(f)
                self.position = data.get("position", 0)
                self.max_position = data.get("max_position", 83329)
                self.speed = data.get("speed", 1000)
                self.target_speed = data.get("target_speed", 1000)
                self.acceleration = data.get("acceleration", 100)
        except (OSError, ValueError):
            return None

    def convert_position(self, unit="rad"):
        if unit == "rad":
            return (self.position / self.steps_per_revolution) * 2 * 3.14159265359
        elif unit == "deg":
            return (self.position / self.steps_per_revolution) * 360
        elif unit == "turns":
            return self.position / self.steps_per_revolution
        else:
            raise ValueError("Invalid unit")

    def convert_speed(self, unit="rad/s", lead_screw_pitch=None):
        if unit == "rad/s":
            return (self.speed / self.steps_per_revolution) * 2 * 3.14159265359
        elif unit == "deg/s":
            return (self.speed / self.steps_per_revolution) * 360
        elif unit == "turns/s":
            return self.speed / self.steps_per_revolution
        elif unit == "linear" and lead_screw_pitch is not None:
            return (self.speed / self.steps_per_revolution) * lead_screw_pitch
        else:
            raise ValueError("Invalid unit or missing lead_screw_pitch")

    def shutdown(self):
        self.timer.deinit()
        self.enable_motor(False)

# Example usage
if __name__ == "__main__":
    try:
        stepper = StepperMotor(step_pin=DO10, dir_pin=DO8, enable_pin=DO9, alarm_pin=DI5, limit_min_pin=DI2, limit_max_pin=DI0, steps_per_revolution=200)

        # Enable the motor
        stepper.enable_motor(True)


        # Move to position
        stepper.move_to(0)

        # Wait a bit and observe holding position
        time.sleep(3)

    except KeyboardInterrupt:
        stepper.shutdown()

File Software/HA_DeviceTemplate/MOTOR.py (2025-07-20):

"""PWM motor driver with simple sequencing support."""

import json
from machine import Pin, PWM
# Import print_control so the custom print replacement is active
try:
    from print_control import custom_print as print #noqa: F401
except Exception:
    pass
import time

class MOTORDriver:
    """Control a bidirectional DC motor using two PWM outputs."""

    def __init__(
        self,
        pwm_pin_A: int,
        pwm_pin_B: int,
        freq: int = 8000,
        cw_range: tuple[int, int] = (0, 65535),
        ccw_range: tuple[int, int] = (0, 65535),
        stop_pwm: int = 0,
        loop_file: str = "motor_loop.json",
    ) -> None:
        """Initialise the driver and load an optional sequence file."""
        self.pwm_a = PWM(Pin(pwm_pin_A, Pin.OUT, pull=Pin.PULL_DOWN))
        self.pwm_a.freq(freq)
        self.pwm_b = PWM(Pin(pwm_pin_B, Pin.OUT, pull=Pin.PULL_DOWN))
        self.pwm_b.freq(freq)
        self.duty_u16 = 0
        self.cw_range = cw_range
        self.ccw_range = ccw_range
        self.stop_pwm = stop_pwm

        self.state = False
        self.standby = True
        self.speed = 0

        self.sequence_index = 0
        self.last_time = time.ticks_ms()
        self.loop_file = loop_file
        self.loop = self.load_loop_from_file() or [
            [0.5, 100],
            [1, -100],
            [0.3, 0],
            [2, 100],
            [2, 0]
        ]

        self.update_pwm()

    def load_loop_from_file(self, *args, **kwargs):
        """Return a sequence list loaded from ``self.loop_file`` or ``None``."""
        try:
            with open(self.loop_file, 'r') as file:
                data = json.load(file)
                if isinstance(data, list) and all(isinstance(item, list) and len(item) == 2 for item in data):
                    print(f"Loaded loop sequence from {self.loop_file}")
                    return data
                else:
                    print(f"Invalid loop format in {self.loop_file}")
        except FileNotFoundError:
            print(f"Loop file {self.loop_file} not found. Using default loop.")
        except Exception as e:
            print(f"Error loading loop file: {e}")
        return None

    def save_loop_to_file(self, loop_data, *args, **kwargs):
        """Persist ``loop_data`` to ``self.loop_file``."""
        try:
            with open(self.loop_file, 'w') as file:
                json.dump(loop_data, file)
                print(f"Loop sequence saved to {self.loop_file}")
        except Exception as e:
            print(f"Error saving loop file: {e}")

    def toggle_state(self, *args, **kwargs):
        """Flip the motor's running state."""
        self.state = not self.state

    def set_standby(self, standby, *args, **kwargs):
        """Enter or leave standby mode."""
        self.standby = standby

    def set_state(self, state, *args, **kwargs):
        """Set running state to ``state``."""
        self.state = state

    def set_speed(self, speed, *args, **kwargs):
        """Set the motor speed in percent (-100..100)."""
        self.speed = speed

    def update_pwm(self, *args, **kwargs):
        """Update PWM outputs based on current state."""
        standby = self.standby
        state = self.state
        speed = self.speed

        if standby or not state or speed == 0:
            self.pwm_a.duty_u16(self.stop_pwm)
            self.pwm_b.duty_u16(self.stop_pwm)
            self.duty_u16 = self.stop_pwm
            return

        self.duty_u16_a = self.map_range(abs(self.speed), 0, 100, *self.cw_range)
        self.duty_u16_b = self.map_range(abs(self.speed), 0, 100, *self.ccw_range)

        if self.speed > 0:  # Clockwise
            self.pwm_a.duty_u16(int(self.duty_u16_a))
            self.pwm_b.duty_u16(self.stop_pwm)
        elif self.speed < 0:  # Anticlockwise
            self.pwm_a.duty_u16(self.stop_pwm)
            self.pwm_b.duty_u16(int(self.duty_u16_b))

    def play_sequence(self, *args, **kwargs):
        """Run the next step of the configured movement sequence."""
        duration, speed = self.loop[self.sequence_index]
        now = time.ticks_ms()
        if time.ticks_diff(now, self.last_time) > int(duration * 1000):
            self.last_time = now
            self.sequence_index = (self.sequence_index + 1) % len(self.loop)
            duration, speed = self.loop[self.sequence_index]
            self.set_speed(speed)
        self.update_pwm()

    @staticmethod
    def map_range(value, in_min, in_max, out_min, out_max):
        """Return ``value`` mapped from one range to another."""
        return (value - in_min) * (out_max - out_min) / (in_max - in_min) + out_min

    def stop(self):
        """Stop the motor and clear PWM outputs."""
        print(f"MOTOR - stop")
        self.set_state(False)
        self.set_speed(0)
        self.update_pwm()

    def deinit(self):
        """Disable PWM peripherals."""
        print(f"MOTOR - deinit")
        self.pwm_a.deinit()
        self.pwm_b.deinit()

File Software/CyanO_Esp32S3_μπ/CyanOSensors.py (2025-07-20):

import _thread
import utime
from machine import Pin
from operator import gt, lt, ge, le, eq, ne
import _thread

class Sensor:
    _instances = []  # Class-level list to track all instances
    _lock = _thread.allocate_lock()  # Create a lock for thread-safe operations

    def __init__(self, pin, condition_func, threshold_value, interval_seconds):
        self.pin = Pin(pin, Pin.IN)
        self.condition_func = condition_func
        self.threshold_value = threshold_value
        self.interval = interval_seconds
        self.result = False
        
        # Use the lock to safely add this instance to the list of instances
        with Sensor._lock:
            Sensor._instances.append(self)
        
        # Start the background check in a new thread
        _thread.start_new_thread(self.check, ())

    def check(self):
        while True:
            read_value = self.pin.value()
            self.result = self.condition_func(read_value, self.threshold_value)
            utime.sleep(self.interval)

    def __bool__(self):
        return self.result

    @classmethod
    def all(cls):
        # You might also want to protect this read operation with the lock,
        # depending on how it's used and what it's used for.
        with cls._lock:
            return all(instance for instance in cls._instances)

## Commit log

2021-04-10 beggining of modelisation for floating lamp module.
    This module is to allow artificial lighting for culture in opaque containers.
    [CostLog.xlsx, clearcontainer.SLDPRT, container Lid.SLDPRT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]
2021-04-11 technicalities for elecrtrocoagulation
    1.4 to 4.3v
2021-04-11 Update nutrition spiruline chlorella.xlsx
    [nutrition spiruline chlorella.xlsx]
2021-04-16 Building up the project's frame and adding details
    [3Dponics-Venturi.SLDPRT, 3Dponics-Venturi.STL, 3Dponics-Venturi.obj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]
2021-04-17 Adding hardware details and frame
    [3Dponics-Venturi.SLDPRT, 3Dponics-Venturi.STL, 3Dponics-Venturi.obj]
2021-04-22 Adding some hardware
    [3Dponics-Venturi.SLDPRT, AC_TubeExtremitiesBearingSlotsWithbridgeSupport.3mf, TubeExtremitiesBearingSlots.SLDPRT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]
2021-04-30 lots of 3d models
    [3mmBelt2x.SLDPRT, 3mmBelt2x.STL, Assem1.SLDASM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]
2021-05-03 some hardware
    [3mmBelt4x.SLDPRT, 3mmBelt4x.STL]
2021-05-08 first sketch completed for microcontroller
    [nutrition spiruline chlorella.xlsx]
2021-05-10 Successful iteration
    the web interface is working.
    the analog input expander is working.
    the pwm output is working(to control the relay board)
    the callback button is working(to produce some actions from commands writen on the web interface)
2021-05-13 controller pcb board for connecting all modules
2021-05-17 making code work with relay board via pca8xxx
2021-06-15 good progress
    [CostLog.xlsx, nutrition spiruline chlorella.xlsx]
2021-08-07 progression update
    [CostLog.xlsx]
2021-08-17 model modif
    [DensitysensorCappt1.SLDPRT, Sonsor Module .SLDASM, electronic frame mount - DensitysensorCappt1-1.STL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]
2022-01-04 BIG UPDATE
    [4-Channel_Relay_Module_Mockup.SLDPRT, 5galBucket.SLDPRT, 6331K85_Compact Round-Face DC Motor.SLDPRT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]
2022-02-06 redesign of the electronics for cheaper simpler
    [OBJ_PCB_FFF_PCB_all_in_one-5Relays_power_motor.obj, OBJ_PCB_FFF_PCB_all_in_one.obj, axel_connector.SLDPRT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]
2025-07-20 Add documentation on new folder layout
    [nutrition spiruline chlorella.xlsx]
2025-07-20 Major Cleanup
    [4-Channel_Relay_Module_Mockup.SLDPRT, 5galBucket.SLDPRT, 6331K85_Compact Round-Face DC Motor.SLDPRT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]
2025-07-20 import example of new structure
    [motor_loop.json]
2025-07-20 Rename HA_CatToy to HA_DeviceTemplate and generalize
    [motor_loop.json]
2025-07-20 Align FFFV2 with HA device template
2025-07-20 data formating
    [Culture_medium_summary.xlsx, HarvestData.xlsx]
